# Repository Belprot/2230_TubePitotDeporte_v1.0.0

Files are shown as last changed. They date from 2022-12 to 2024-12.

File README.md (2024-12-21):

# 2230_TubePitotDeporte

Electronic system designed to measure historical aircraft stall data and transmit them via Bluetooth to an application that displays and records the values.

## [Project report](doc/Versions/2230_TubePitotDeporte_Rapport_Final_v1_0_0.pdf)

## Project poster
1696542741941-cd63cdde-709c-4f6f-9c06-00f6e5ce87d3_1

## 3D PCB pictures
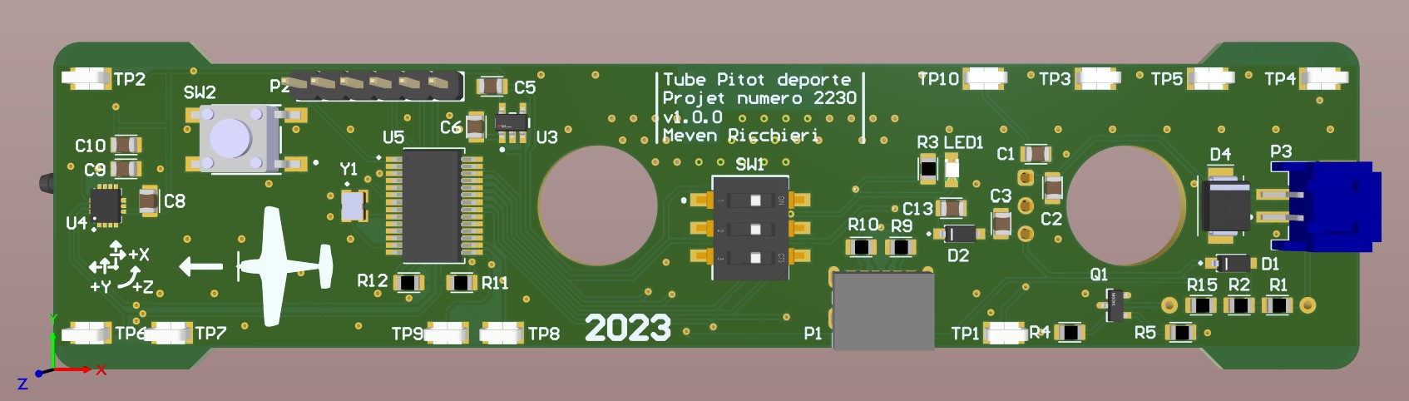
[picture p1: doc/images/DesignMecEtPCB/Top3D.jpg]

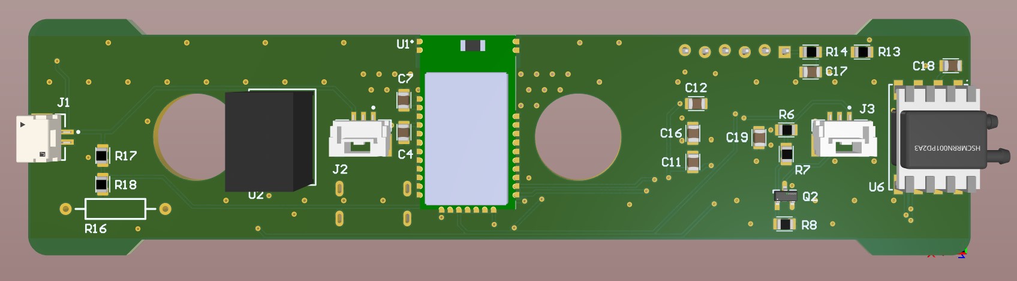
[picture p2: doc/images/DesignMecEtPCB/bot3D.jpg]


## 3D Integration
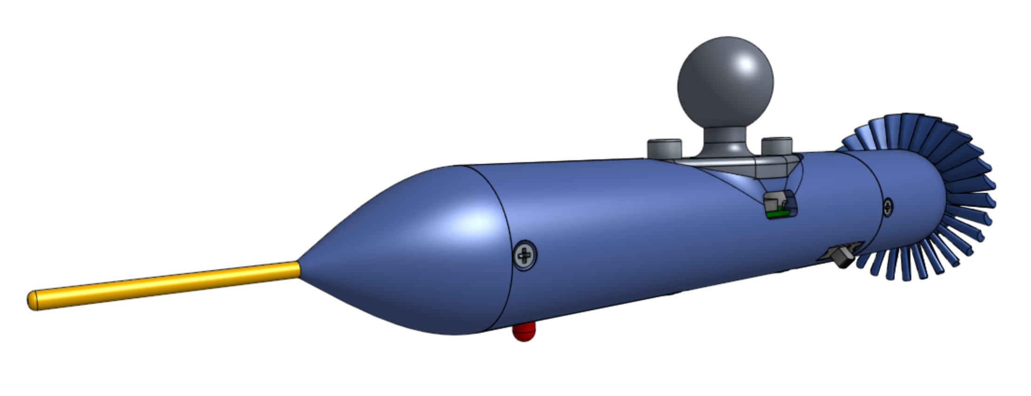
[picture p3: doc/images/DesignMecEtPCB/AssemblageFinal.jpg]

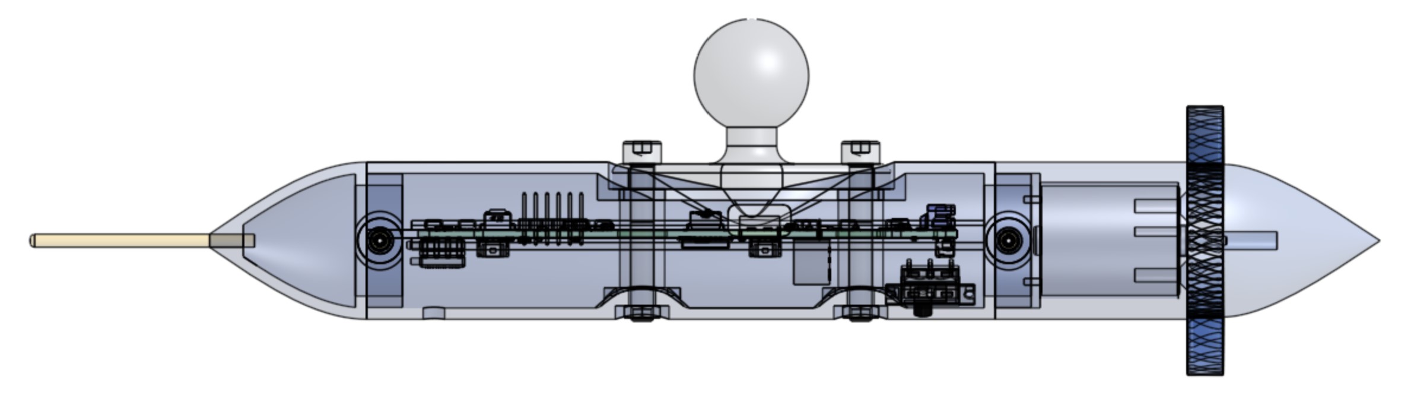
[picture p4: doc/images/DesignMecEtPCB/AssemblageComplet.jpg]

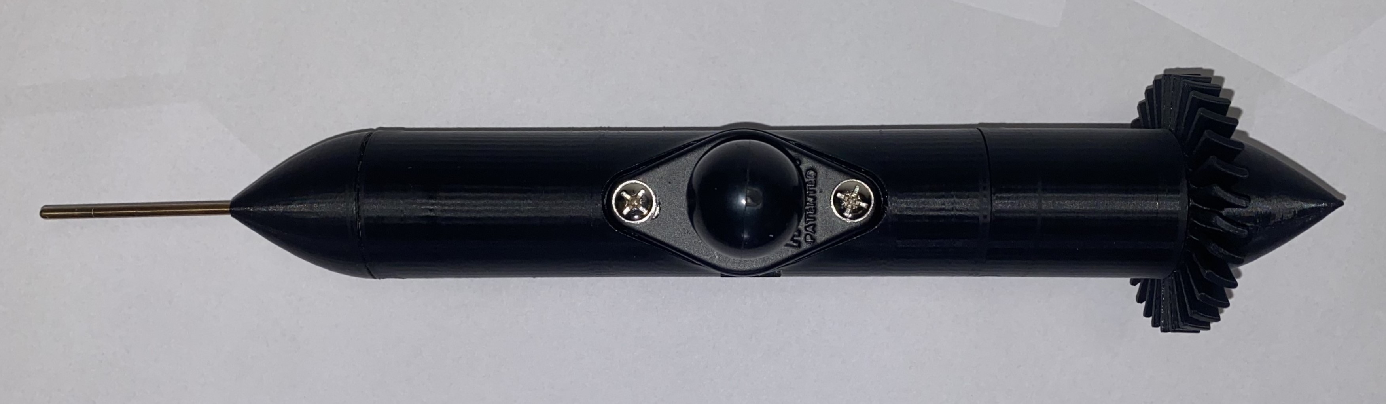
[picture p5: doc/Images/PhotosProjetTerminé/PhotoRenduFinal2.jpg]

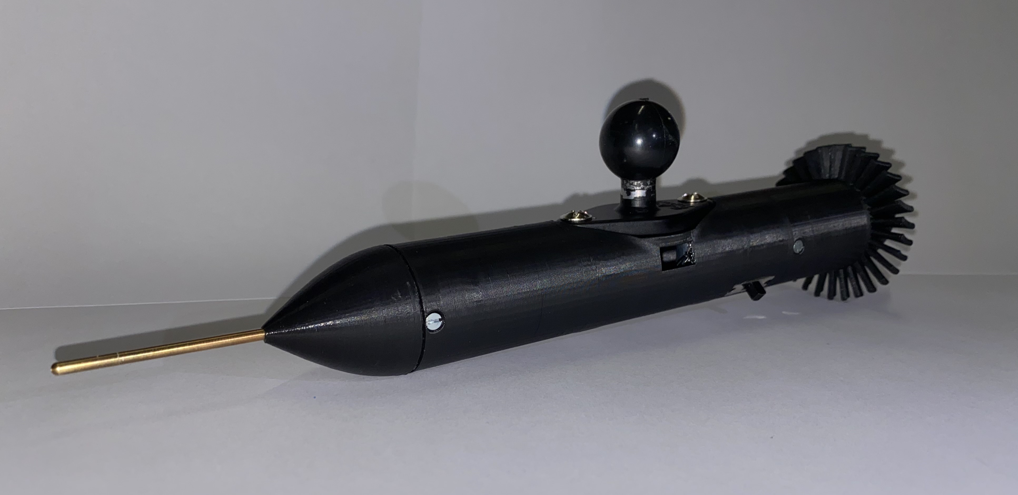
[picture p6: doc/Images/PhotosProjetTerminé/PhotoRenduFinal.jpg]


## Application preview
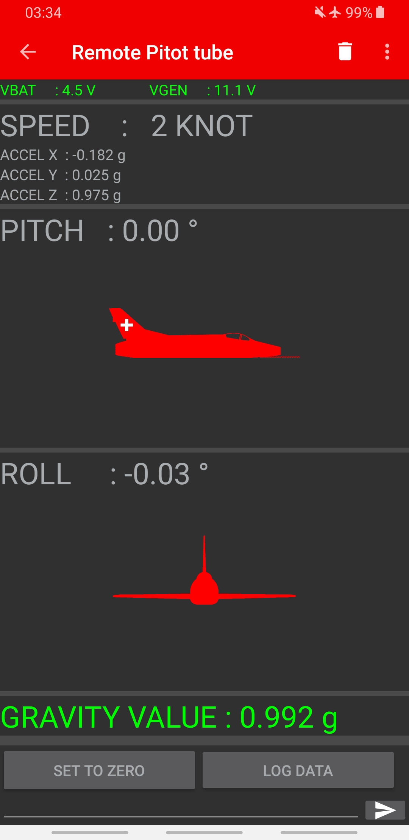
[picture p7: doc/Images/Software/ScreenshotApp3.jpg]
Application preview


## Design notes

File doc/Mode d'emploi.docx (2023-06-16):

# Mode d’emplois :

1. Branchez le connecteur de la batterie.
2. Vissez le support pile au boitier principale.
3. Allumez le système à l’aide du switch.
4. Appairez le système à l’appareil Android.
5. Lancez l’application dédiée.

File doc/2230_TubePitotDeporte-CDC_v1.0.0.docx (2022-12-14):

# Projet ETML-ES - Cahier des charges

Tube Pitot déporté

2230

A remplir par l'initiateur / porteur de projet

Entreprise/Client: | | Département:
Demandé par (Prénom, Nom): | | Date:

A remplir par le gestionnaire de projet (étudiant)

Auteur (ETML-ES): | Meven Ricchieri | Filière: | SLO
| | Date: | 16.11.2022

# 1 But du projet

Le but du projet consiste à développer un système permettant de détecter l’angle d’incidence et la vitesse au décrochage d’un avion. La fixation de ce système doit être flexible afin de pouvoir l’installer sur différents types d’avions. L’emplacement de fixation ne doit pas se trouver dans le flux d’air provenant de l’hélice afin d’éviter que la mesure de vitesse ne soit faussée. Il doit également être miniaturisé au maximum afin de produire le minimum de trainée possible et de ne pas dépasser un poids de 500g. Les données acquises par les capteurs doivent être transmises de la partie déportée à un appareil Android se trouvant dans le cockpit de l’avion au travers une communication sans fil. L’appareil Android doit traiter et afficher les données reçues, si possible graphiquement (optionnel).

## 1.1 Schéma de principe

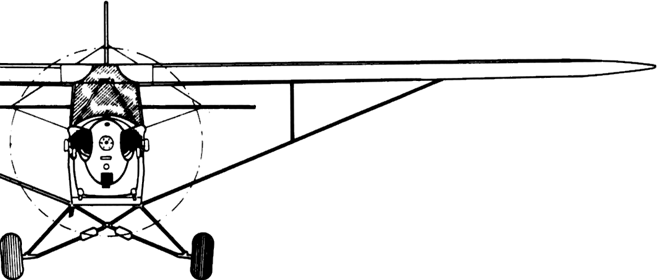
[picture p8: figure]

3

1 : Produit

2 : Appareil Android

3 : Signaux BLE (Bluetooth Low Energy)

1

2

Figure 1 -

# 2 Spécifications du projet

## 2.1 Schéma bloc

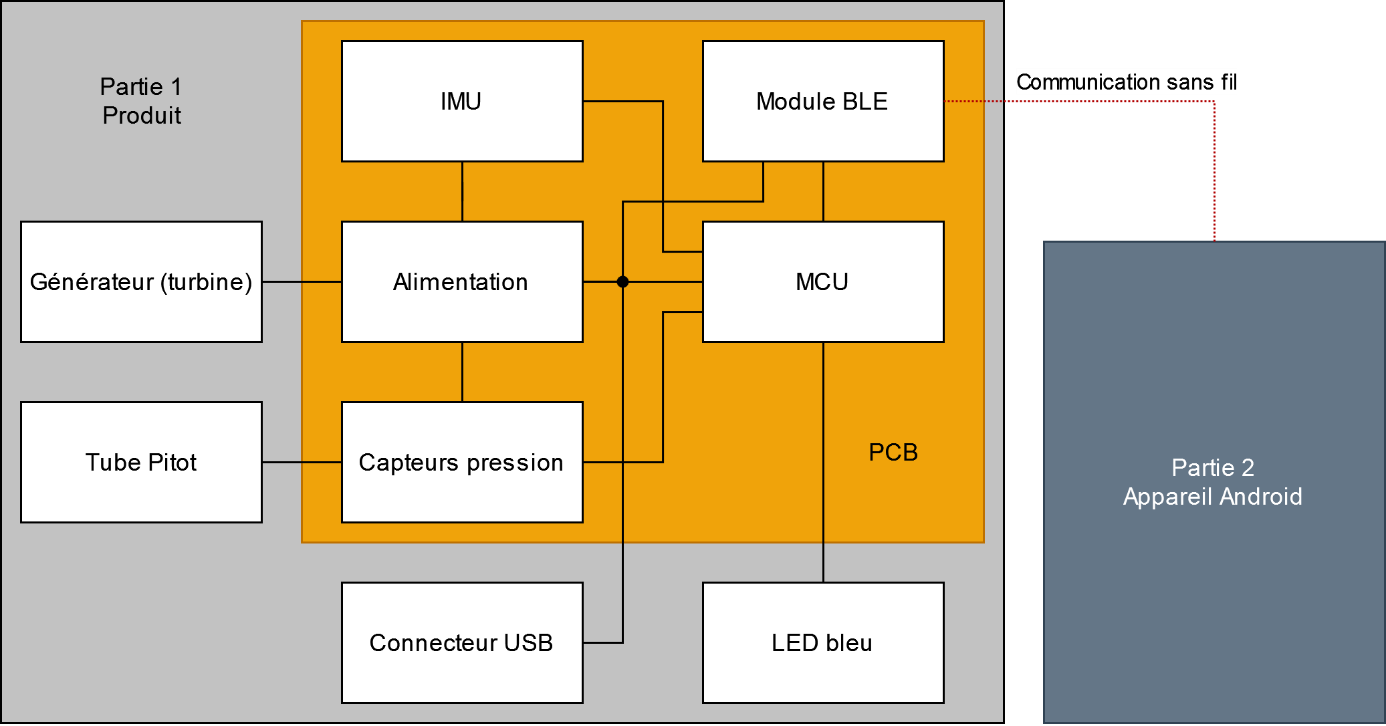
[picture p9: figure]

Figure 2 - Schéma bloc

### 2.1.1 Descriptions simples des blocs

- Générateur (turbine), l’idée est d’intégrer un générateur-turbine, montés à l’arrière du produit (voir Figure 2) afin de générer l’électricité nécessaire au système. Dans le cas où la réalisation mécanique de cela serait trop difficile, une batterie ou pile serait l’alternative.
- LED bleue, permettra d’indiquer l’état du système à un moment donné, elle devra être visible depuis l’intérieur du cockpit. Le comportement sera le suivant :
  - LED éteinte, le système non alimenté.
  - Simple clignotement à une fréquence de 0.5Hz, le système n’est pas appairé à un périphérique Bluetooth.
  - Double clignotement à une fréquence de 0.5Hz, le système est appairé à un périphérique Bluetooth et fonctionnel.
- Connecteur USB, le connecteur permettra d’alimenter le système afin de le tester lorsqu’il est au sol.
- Tube Pitot, servira d’entrée d’air pour les capteurs de pression.
- Capteurs pression, ces capteurs liront les valeurs de la pression statique et totale pour ainsi calculer la vitesse air.
- Alimentation, l’alimentation transformera la tension provenant de la source d’énergie en une tension régulée et stable.
- IMU, la centrale inertielle servira à mesurer les vecteurs des vitesses angulaires et les accélérations.
- MCU, le microcontrôleur va être le cerveau du produit, il sera responsable de commander tous les autres composants.
- Module BLE, le module Bluetooth Low Energy permettra d’établir une communication basse consommation entre le produit et l’appareil Android. C’est par le biais de cette liaison que seront transmises toutes les données.
- Appareil Android, l’appareil recevra, traitera et affichera les données sur son écran. Il permettra également d’envoyer des commandes tels que la fréquence d’envoi ou d’autres paramètres.

Les blocs seront décrits en détail dans la pré-étude.

## 2.2 Croquis du produit

L’intégration du système se fera dans un cylindre à l’arrière du tube Pitot comme représenté ci-dessous (vue en coupe). Dans le cas où la vitesse de rotation du générateur est trop élevée, l’ajout d’un carénage permettrait de diminuer la vitesse du flux d’air en augmentant la section de sortie par rapport à l’entrée. La fixation se réalisera à l’aide d’une boule style RAM-Mounts.

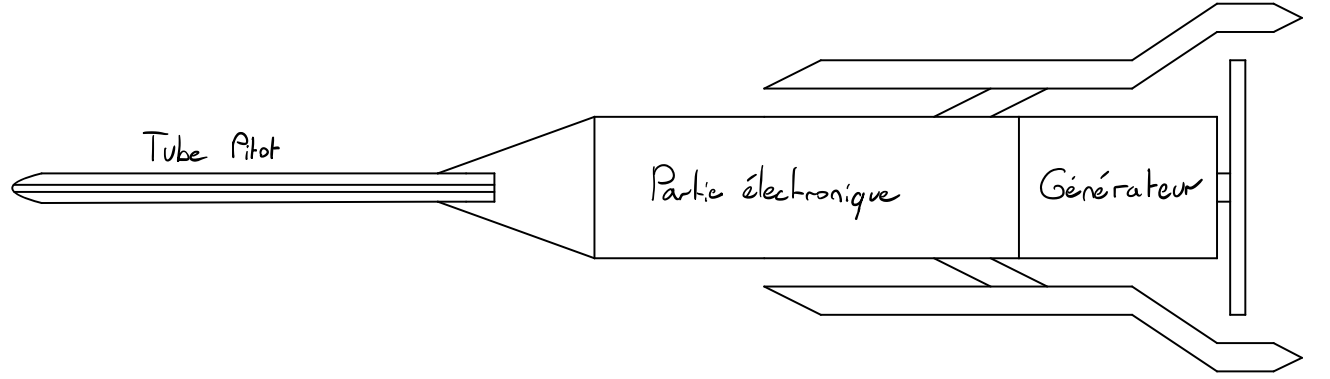
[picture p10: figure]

Figure 3 - Croquis du produit (vue en coupe)

# 3 Tâches à réaliser

- Pré-étude
- Dimensionnement, design et réalisation du schéma
- Commande des composant et du matériel
- Réalisation du PCB
- Design de l’assemblage mécanique avec fixations
- Montage du PCB
- Réalisation du software du MCU et de l’application Android
- Impression 3D ou usinage de la partie mécanique
- Mise en service et tests

# 4 Deadlines principales

- 16 novembre 2022 : Début du projet
- 07 décembre 2022 : Rendu de la pré-étude
- 14 décembre 2022 : Présentation de la pré-étude
- 25 janvier 2023 : Rendu du design
- 01 février 2023 : Présentation du design
- 22 mars 2023 : Rendu des fichiers de fabrication PCB
- 14 juin 2023 : Rendu de toute la documentation finale
- 21 juin 2023 : Présentation finale

## 4.1 Planning

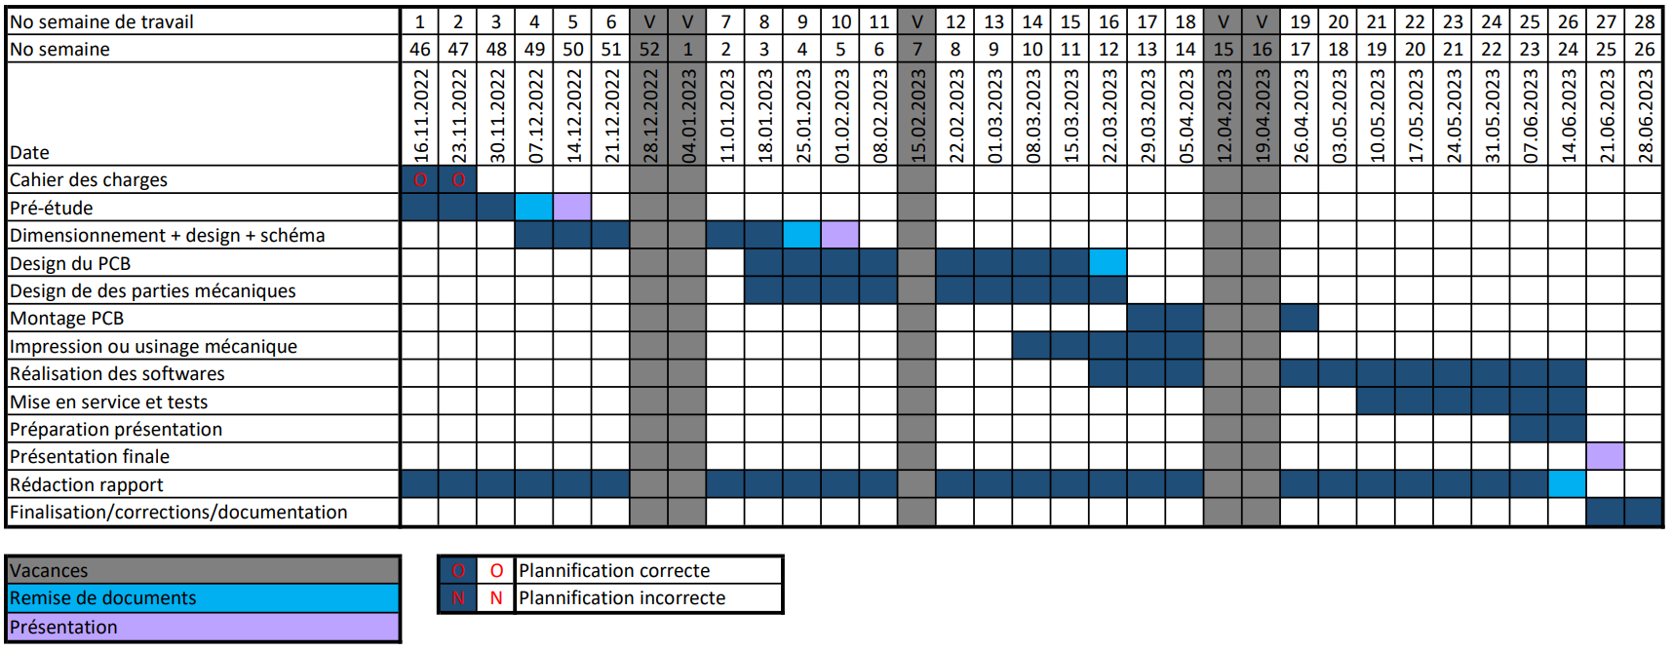
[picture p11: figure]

Figure 4 - Planning

# 5 Livrables

- Les fichiers sources de CAO électronique et mécanique
- Tout le nécessaire pour fabriquer un (1) exemplaire hardware :
  - Fichiers de fabrication (GERBER)
  - Liste de pièces avec références (BOM)
  - Implantation des composants
  - Dessins mécaniques
- Les fichiers sources de programmation du microcontrôleur (.c/.h)
- Tout le nécessaire pour programmer les microcontrôleurs (.hex)
- Les fichiers sources de programmation Android.
- Tout le nécessaire à l’installation de programmes sur Android.
- Un mode d’emploi du produit
- Une estimation des coûts du projet
- Un rapport contenant toutes les informations du design du produit.
- Un prototype monté et fonctionnel
- Une application Android permettant d’afficher les données :
  - Affichage numérique
  - Affichage graphique (optionnel)

JMO – Nov 20222230_TubePitotDeporte-CDC-v1.0.0.docxPage 4

ECOLE SUPERIEURE PROJ – SLO

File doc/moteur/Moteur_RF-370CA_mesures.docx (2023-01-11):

Données fournies par le fabriquant du moteur :

Introduction :

Les mesures sont réalisées en deux parties, la première permet d'obtenir des valeurs précises de la vitesse de rotation en fonction de la tension d'alimentation et la deuxième permet de connaitre la tension générée lorsque les vitesses sont les mêmes qu'à la première partie.

Méthode de mesures partie 1 :

Le moteur RF-370A-15370 est connecté à une alimentation DC, celle-ci délivre une tension de 0 à 12V par pas de 1V. A chaque saut de tension, la vitesse est mesurée à l'aide d'un tachymètre optique.

Schéma de mesures partie 1 :

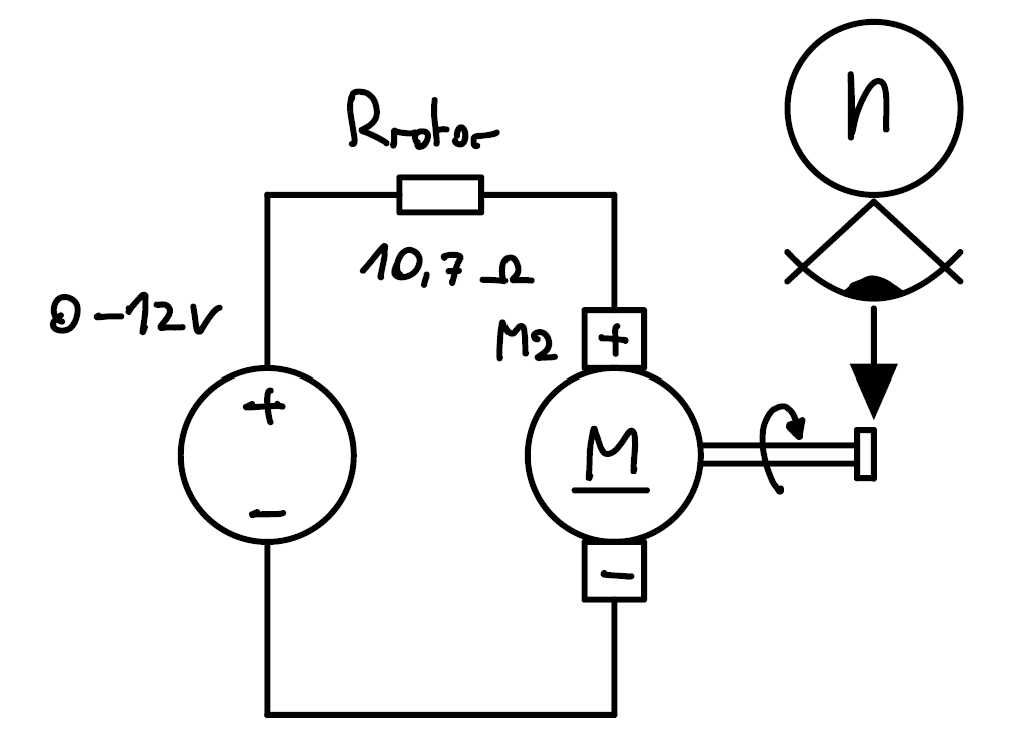
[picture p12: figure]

Uin

Résultats partie 1 :

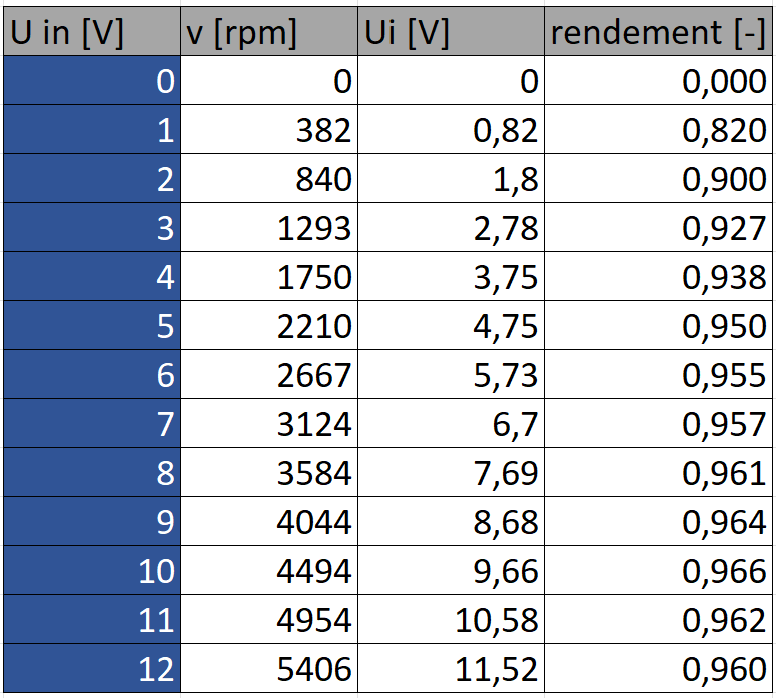
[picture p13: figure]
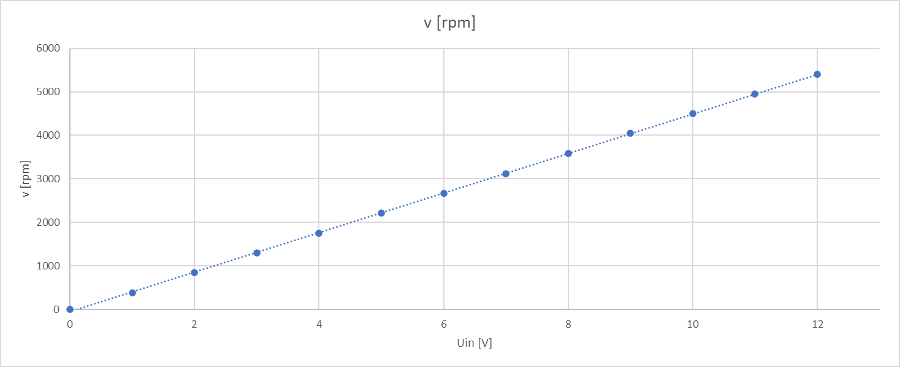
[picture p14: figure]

Méthode de mesures partie 2 :

Pour cette deuxième partie, le un banc de test est composé d’un deuxième moteur DC qui permet d’entrainer le moteur RF-370A-15370. Le moteur M1 est alimenté avec une tension DC alors que le moteur M2 (RF-370A-15370) génère une tension en fonction de sa vitesse de rotation.

Schéma de mesure partie 2 :

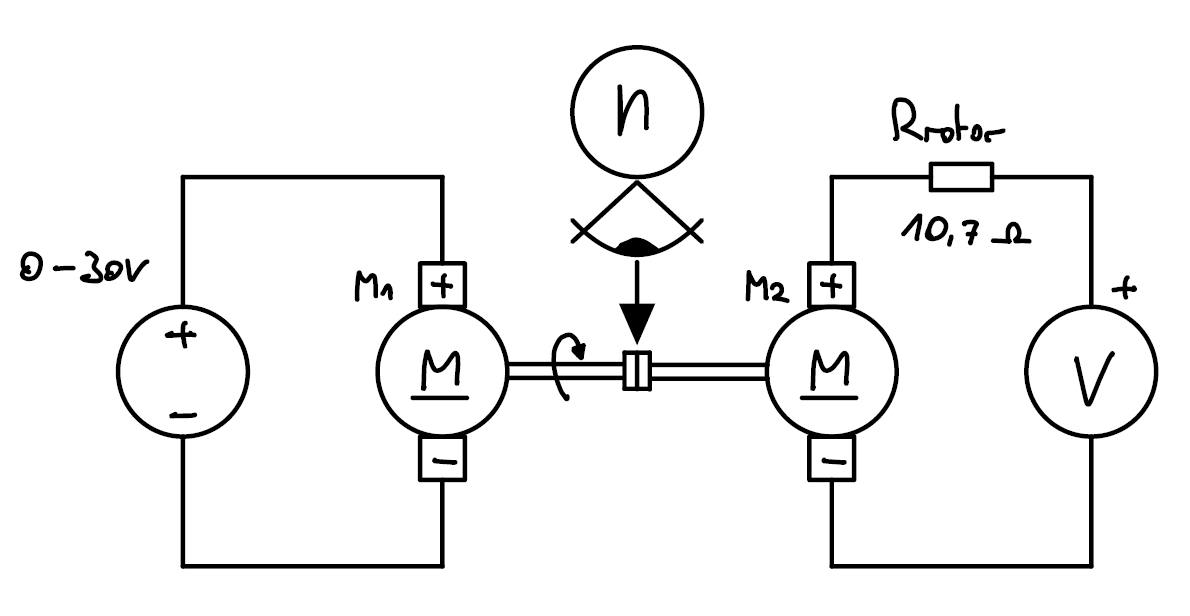
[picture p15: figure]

UT

Résultats partie 2 :

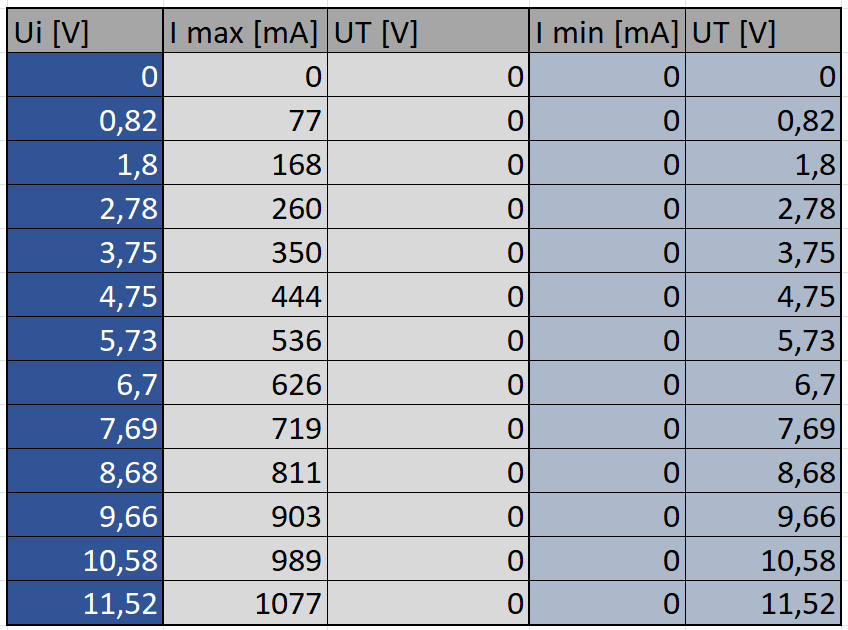
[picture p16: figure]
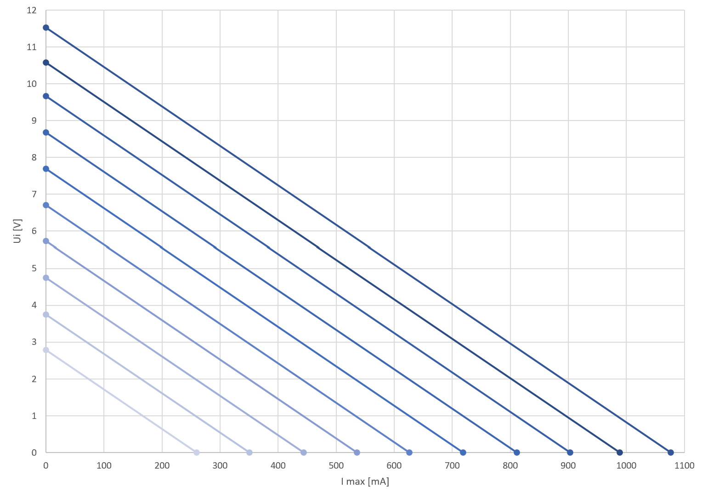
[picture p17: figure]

Delémont, le 27 décembre 2022 Meven Ricchieri

Caractérisation moteur RF-370A-15370 27.12.2022

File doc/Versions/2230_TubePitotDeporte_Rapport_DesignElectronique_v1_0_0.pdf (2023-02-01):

# Tube Pitot déporté

Détection de l’angle d’incidence au décrochage d’un avion par mesure de la vitesse et des accélérations

Meven Ricchieri
2022 - 2023
Numéro de projet | : | 2230
Responsable | : | M. Juan José Moreno
Mandataire | : | M. Vincent Seguin (pour AMPA)

2230_TubePitotDeporte-Rapport_v1.0.0

## Table des matières

1 Cahier des charges | 2
2 Pré-étude | 2
3 Design électronique | 9
4 Annexes | 19

## 1 Cahier des charges

Le but du projet consiste à développer un système permettant de détecter l’angle d’incidence et la vitesse au décrochage d’un avion. La fixation de ce système doit être flexible afin de pouvoir l’installer sur différents types d’avions. L’emplacement de fixation ne doit pas se trouver dans le flux d’air provenant de l’hélice afin d’éviter que la mesure de vitesse ne soit faussée. Il doit également être miniaturisé au maximum afin de produire le minimum de traînée possible et de ne pas dépasser un poids de 500g. Les données acquises par les capteurs doivent être transmises de la partie déportée à un appareil Android se trouvant dans le cockpit de l’avion au travers une communication sans fil. L’appareil Android doit traiter et afficher les données reçues, si possible graphiquement (optionnel).

Le cahier des charges complet se trouve en annexes.

## 2 Pré-étude

### 2.1 Contexte

Cette pré-étude consiste à mener des recherches qui conduirons à une décision de lancer ou non le projet. Cette décision va reposer sur les difficultés de réalisation électrique, mécanique et software. Elle va aussi permettre d’imaginer et de comparer les différentes manières de réaliser les tâches et ainsi choisir la meilleure.

### 2.2 Schéma de principe

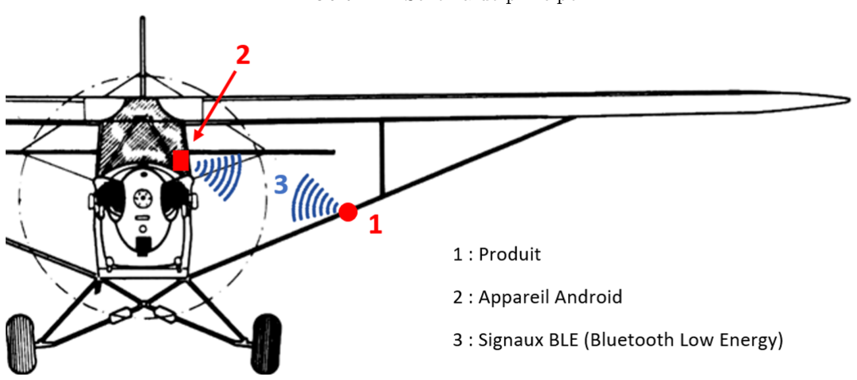
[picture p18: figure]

Figure 1 – Schéma de principe

### 2.3 Schéma bloc détaillé

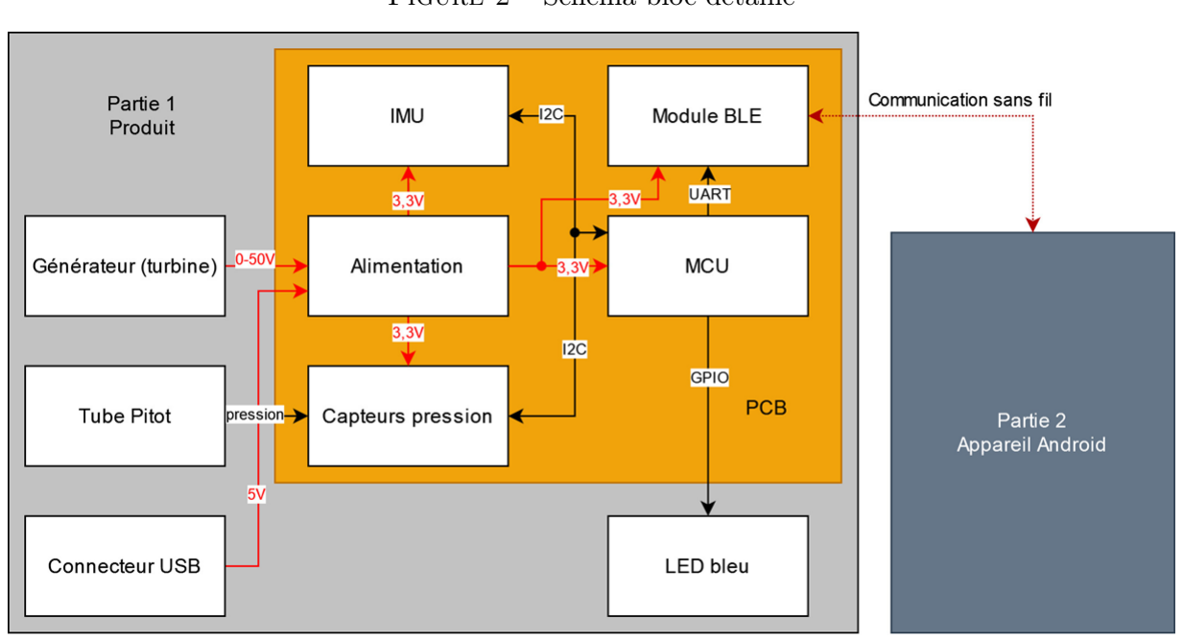
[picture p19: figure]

Figure 2 – Schéma bloc détaillé

### 2.4 Descriptions des blocs détaillées

### 2.4.1 Bloc Générateur (turbine)

L’intérêt d’utiliser un générateur comme source d’énergie permet de simplifier l’utilisation du système, il n’y aura aucune maintenance à effectuer ou de batterie à charger. L’énergie cinétique de l’air en mouvement, par rapport à l’avion, vas être captée par les aubes de la turbine axée à un générateur, ce qui va produire une tension. Le système va se mettre en marche une fois que l’axe du générateur-turbine aura atteint une certaine vitesse de rotation. Plus la vitesse sera grande, plus la tension générée sera élevée. Un simple moteur DC, va permettre de transformer cette énergie mécanique en énergie électrique. Il est possible d’utiliser d’autres technologies comme les moteurs brushless, qui ont un rendement bien meilleur, mais cela complexifie le circuit et augmente le prix. Dans ce projet, le rendement n’est pas primordial car le système ne consommera que très peu d’énergie.
Ut(V ) = n
kn
− Rmot ∗ IL [2] | (1)

où :
Ut | = | Tension aux bornes du moteur DC (V)
kn | = | Constante de vitesse du moteur DC (rpm/V)
Rmot | = | Résistance aux bornes du moteur DC (Ω)
n | = | Vitesse moteur DC (rpm)
IL | = | Courant de charge (I)

Puisque la valeur de la tension géné-

rée est dépendante de la vitesse air de l’avion, celle-ci ne sera jamais stable. Il faudra donc la transformer et la réguler avant de la transmettre aux composants électroniques, ce à quoi le bloc "Alimentation" sera destiné.

N’ayant pas de grandes connaissances dans le dimensionnement et le design de générateur-turbines, des recherches plus poussées seront nécessaires afin de rendre le système performant. Pour me faire une première idée, j’ai dessiné et imprimé une première turbine composée de 13 aubes puis j’ai effectué quelques tests. A l’aide d’un moteur DC, j’ai réussi à générer une tension d’environ 3V à une vitesse de 80km/h.

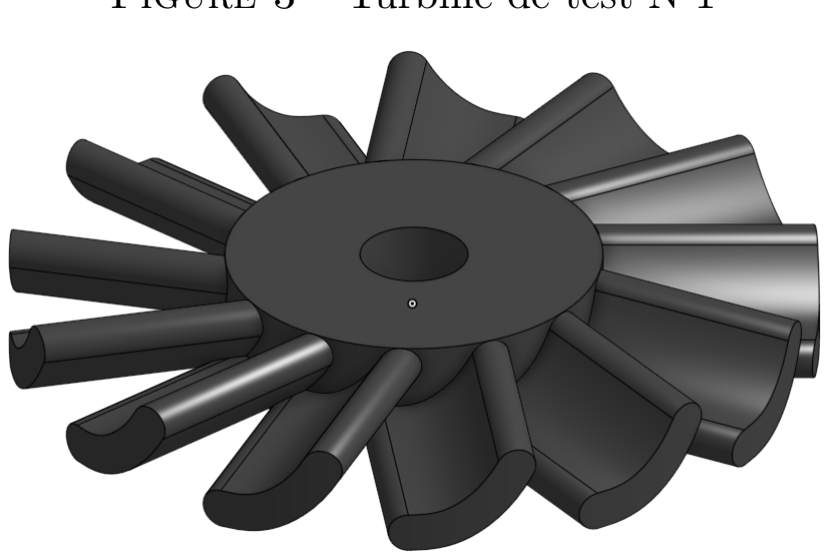
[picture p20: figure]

Figure 3 – Turbine de test N°1

### 2.4.2 Bloc Capteur de pression

Le système sera équipé d’un capteur de pression différentielle qui permettra de mesurer la différence entre la pression statique et la pression totale. "La pression statique, dans un fluide en mouvement, est la pression que mesure un capteur qui se déplace à la même vitesse que le fluide" [3]. "La pression totale dans un fluide (eau, air, etc.) est la somme de la pression statique, de la pression dynamique, et de la densité volumique d’énergie potentielle de gravité" [4]. Grâce aux valeurs ainsi mesurées, il sera possible de calculer la vélocité du fluide, ce qui correspondra à la vitesse air de l’avion. Pour des vitesses inférieures à Mach 0.3 (200 nœuds), l’effet de compressibilité du fluide peut être négligé [5].

v(m/s) = s
2 ∗ (pt − ps)
ρ
[5] (2)

où :
v | = | Vélocité du fluide (m/s)
pt | = | Pression totale (Pa)
ps | = | Pression statique (Pa)
ρ | = | Masse volumique du fluide (kg/m³
)

### 2.4.3 Bloc Tube Pitot

Comme expliqué au point précédent, la vitesse se calcule grâce à la pression statique et totale, pour que le capteur différentielle ait accès à ces deux pressions, il faut ajouter deux entrées d’air. Ces entrées doivent être placées correctement car dans le cas contraire, la vitesse calculée ne sera pas correcte. L’entrée de la pression statique doit être perpendiculaire à l’écoulement local du fluide (non perturbé) alors que celle de la pression totale doit être parallèle à ce flux. Il existe 3 tubes différents, le premier, appelé tube Pitot simple, est simplement un tube perforé en son centre faisant office d’entrée d’air pour la pression totale. Le second, appelé sonde statique, est perforé latéralement permettant l’entrée d’air pour la pression statique. Le troisième est une combinaison des deux premiers, il dispose d’une entrée pour la pression totale et d’une autre pour la pression statique. L’idéal serait d’utiliser ce dernier car il simplifierait l’implémentation mécanique du système. Les deux sorties du tube seraient reliées au capteur de pression différentielle par des tuyaux. Dans le cas ou un tube Pitot simple serait utilisé, il serait nécessaire de perforer le boîtier du produit afin d’avoir accès à la pression statique. La décision du type de tube sera effectué lors du design mécanique car il n’influence aucunement la conception électronique.

Figure 4 – Types de tubes Pitot

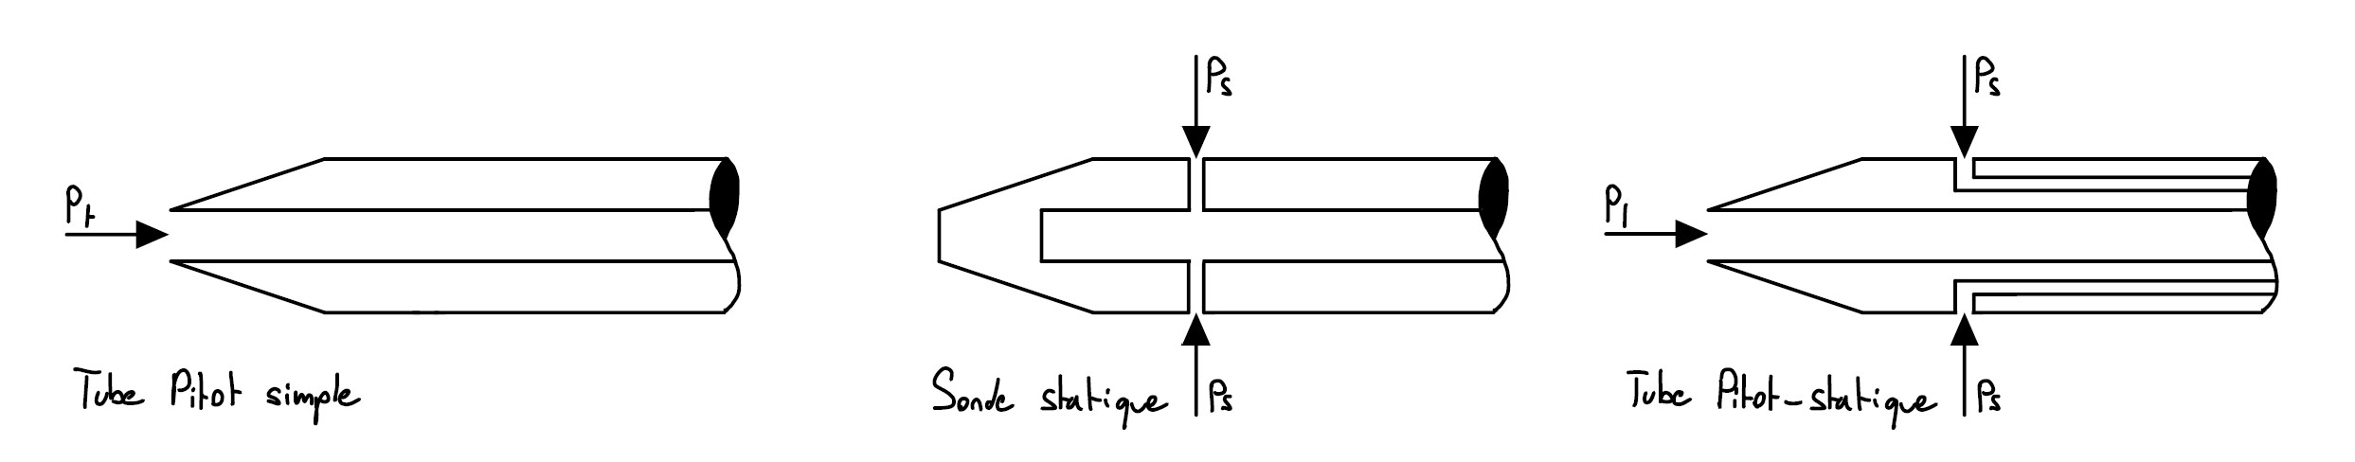
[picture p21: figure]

### 2.4.4 Bloc IMU

La centrale inertielle comportera 6 capteurs, 3 gyromètres et 3 accéléromètres. "Les gyromètres mesurent les trois composantes du vecteur vitesse angulaire (vitesses de variation des angles de roulis, de tangage et de lacet. Les accéléromètres mesurent les trois composantes du vecteur force spécifique. La force spécifique est la somme des forces extérieures autres que gravitationnelles divisée par la masse" [1]. C’est grâce à ses capteurs qu’il sera possible de détecter le moment où l’avion commence à décrocher. La plupart de ces IMUs ont également un capteur de température intégré, la mesure de cette grandeur peut être intéressante puisqu’elle a une influence sur la valeur de la pression.

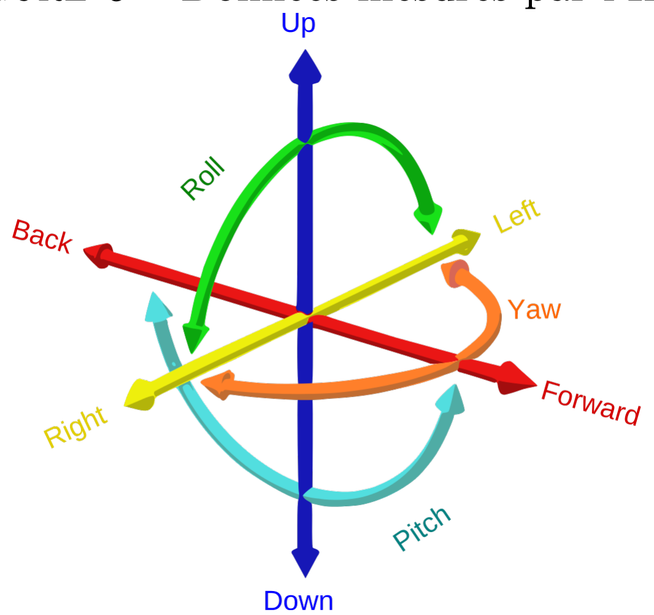
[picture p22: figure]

Figure 5 – Données mesurés par l’IMU

### 2.4.5 Bloc Connecteur USB

Étant donné que le système n’aura pas de source d’énergie interne, un connecteur USB-C sera implémenté afin de pouvoir tester la communication ainsi que les capteurs, en amont du vol. Il permettra également d’alimenter le système lors de son installation sur l’avion, car il devra être positionné correctement à l’horizontale pour que les mesures soient fiables.

### 2.4.6 Bloc Module BLE

Le transfert de données entre le produit et l’appareil Android, se fera au travers d’une communication sans fil Bluetooth Low Energy (BLE). Cette variante de Bluetooth permet de réduire significativement sa consommation par rapport au mode normal. Il sera tout de même possible qu’un module permettant de choisir le mode de fonctionnement soit implémenté. Les données transmises du produit à l’appareil Android seront principalement les valeurs lues par les capteurs alors que celle provenant de l’appareil seront plutôt des commandes ou réglages.

### 2.4.7 Bloc LED bleue

Comme énoncé dans le CDC, la LED bleue va permettre d’indiquer l’état du système. La LED éteinte va signifier que le système n’est pas alimenté. Un clignotement toute les 2 secondes correspondra au système alimenté mais non appairé à un périphérique Bluetooth et finalement, 2 clignotements toute les 2 secondes correspondra à l’état fonctionnel, appairé et transmettant les données. La LED devra être visible de jour donc son emplacement et son intensité lumineuse devront être correctement défini.

### 2.4.8 Bloc MCU

Le microcontrôleur sera obligatoirement un modèle 32Bit du fabriquant Microchip. Il va faire le lien entre tous les périphériques implémentés, c’est à dire les composants d’entrées, IMU et capteur de pression et ceux de sortie, module BLE et LED. Selon les recherches effectués précédemment, le microcontrôleur devra au minimum contenir,

— Un module UART pour la communication avec le module Bluetooth
— Un module I2C pour la communication avec l’IMU et le capteur de pression — Une PIN GPIO pour le contrôle de la LED

### 2.4.9 Bloc Alimentation

Puisque la grande majorité des composants nécessaires, tel que le PIC ou les capteurs, fonctionnent avec une tensions de 3.3V, il faudra donc que la sortie de ce bloc soit proche de cette valeur. Le générateur va produire une tension bien supérieur à 3.3V, donc la meilleure option est d’utiliser un convertisseur Buck afin de l’abaisser. Il permettra d’avoir un bien meilleur rendement qu’un régulateur linéaire et donc limiter la consommation.

Composant | min | max
Module BLE (consommation non continue) Microcontrôleur Capteur pression différentielle LED (consommation non continue) Centrale inertielle | 5mA 5mA 3mA 10mA 1mA | 10mA 10mA 4mA 20mA 3mA
Total | 24mA | 47mA

La consommation totale devrait se situer entre 24mA et 47mA

### 2.4.10 Bloc Appareil Android

Toutes les données obtenues au travers de la communication sans fil seront traitées et affichées sur l’écran de l’appareil. Ces données seront affichées sous forme numérique et dans l’idéal, sous forme graphiques, mais cela reste optionnel. L’application permettra d’envoyer certaines commandes au produit en appuyant sur les différents boutons qui seront affichés. Il sera aussi possible d’ajouter une valeur d’offset aux mesures pour compenser une éventuelle erreur.

### 2.5 Design mécanique

Comme expliqué dans le cahier des charges, l’idée est d’adapter tout le système pour qu’il puisse se trouver dans un cylindre à l’arrière du tube Pitot. Le boîtier et les autres parties mécaniques seront imprimé en une matière plastique selon la disponibilité de matériaux de l’école. L’idéal serait d’utiliser de l’acrylonitrile butadiène styrène (ABS) car ses caractéristiques mécaniques sont bien supérieures à l’acide polylactique (PLA). La grosse difficulté va être de miniaturiser le design du PCB afin de rendre la section du tube la plus mince possible. Le système de fixation sera réalisé grâce à une boule style RAM-Mounts vissé au boîtier.

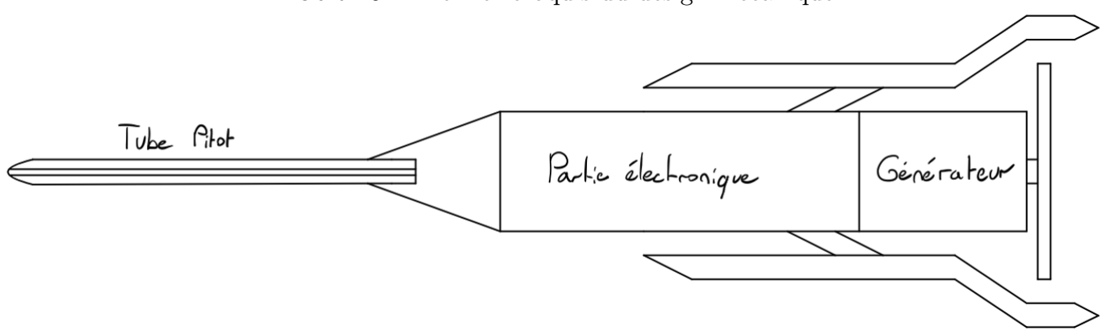
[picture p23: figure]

Figure 6 – Premier croquis du design mécanique

### 2.6 Estimation du prix

L’estimation du prix est actuellement difficile car certains choix doivent encore êtres pris et la disponibilité des composants peut avoir une influence, j’ai donc mis un plage de prix.

Composant | min | max
Générateur (moteur DC) Turbine (ABS) Capteur pression différentielle Tube Pitot Centrale inertielle Connecteur USB-C Module Bluetooth LED MCU Convertisseur Buck Boîtier (ABS) Boule RAM-Mounts PCB | 5.-0.5.-30.-0.-5.-1.-5.-0.5.-1.-3.-1.-15.-50.- | 50.-1.-70.-30.-12.-3.-15.-3.-3.-8.-2.-25.-75.-
Total | 126.- | 396.-

Le prix devrait se situer entre 126.- et 396.-

### 2.7 Faisabilité du projet

D’après les informations trouvées, le projet est totalement réalisable. Il y aura sans doutes quelques difficultés au niveau du dimensionnement de la partie turbine-générateur.

## 3 Design électronique

### 3.1 Introduction

La partie Design électronique consiste à réaliser le schéma électrique, choisir les composants et réaliser les dimensionnements nécessaires. Certaines modifications ont suivi la présentation de la pré-étude. Ceux-ci concernent :
- la source d’alimentation
- la régulation de tension

### 3.2 Générateur

Selon l’estimation de consommation totale effectuée lors de la pré-étude, il est maintenant possible de calculer approximativement la puissance minimum que le générateur devra délivrer au système.

P(W) = U ∗ I | (3)

où :
P | = | Puissance nécessaire (W)
U | = | Tension du circuit (V)
I | = | Courant consommé (A)

Avec la formule (3) :
| | P(W) = 3.3 ∗ 0.047 = 0.1551W = 155mW

Les 155mW correspondent à la puissance maximale approximative consommée après transformation, ce qui signifie qu’il y aura quelques pertes au niveau des abaisseurs de tension. Afin de ne pas avoir de mauvaises surprises, j’ai décidé de prendre une certaine marge, au lieu de 155mW, la puissance sera de 250mW. Cette puissance étant tout de même très faible, le système sera capable de fonctionner même à faibles vitesses tant que la tension minimale est atteinte. Ayant effectué des tests lors de ma pré-étude avec un moteur 3VDC et une première turbine, mon professeur M.Moreno m’en a fourni un différent, RF-370A-15370, fonctionnant jusqu’à une tension nominale de 12VDC. Pour vérifier si ce moteur pourra être utilisé, j’ai réalisé quelques mesures et calculs afin de visualiser les lignes de tension-courant du générateur.

Figure 7 – Lignes tension-courant du générateur

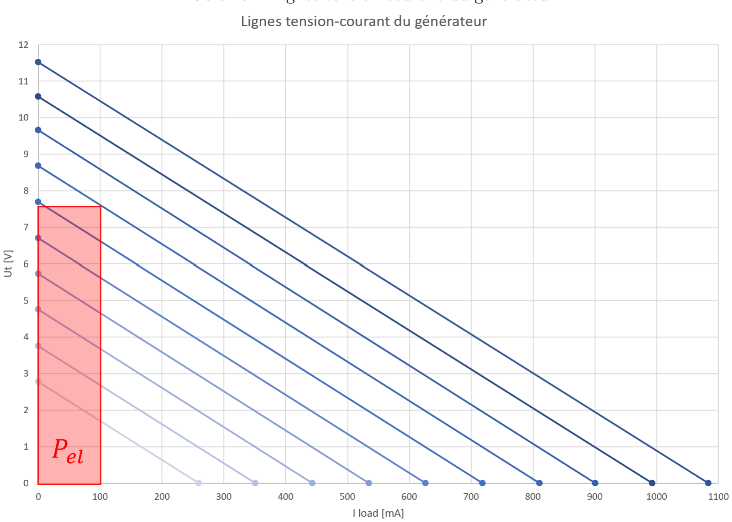
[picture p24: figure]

Le rectangle rouge sur la figure 7 permet de visualiser la puissance électrique. Avec celle-ci nous pouvons savoir quelle tension sera disponible au borne du moteur en fonction de la vitesse de rotation (tension à vide) et du courant consommé. Le rectangle actuel montre que la tension est d’environ 7.8V lorsque la tension à vide est de 8V (environ 3600rpm) avec un courant consommé de 100mA.
Avec la formule (3) :
P(W) = 7.8 ∗ 0.100 = 0.78W = 780mW

Avec ce calcul, il est évident que le moteur correspond parfaitement puisque celui-ci devra fournir bien moins de puissance au système. Ce moteur là est plus adapté car il génère une tension supérieurs à la tension après régulation, 3.3VDC.

Le problème de ce moteur est qu’au moment ou sa vitesse est trop élevée, cela peut le dégrader. J’ai donc décidé d’ajouter au schéma un système de freinage. La tension générée par le moteur passera par un pont diviseur avant d’entrer dans une entrée analogique du MCU. Une diode de protection permettra de court-circuiter la surtension lorsqu’elle est trop importante pour protéger le MCU. Une sortie PWM sera connectée à la gate d’un N-MOSFET afin de court-circuiter le moteur afin de le freiner lorsque la lecture de l’entrée analogique indiquera que la vitesse est trop élevée. La tension entrant dans le MCU ne pourra pas dépasser la tension max de 3.3V.

Figure 8 – Générateur, circuit de mesure et de freinage

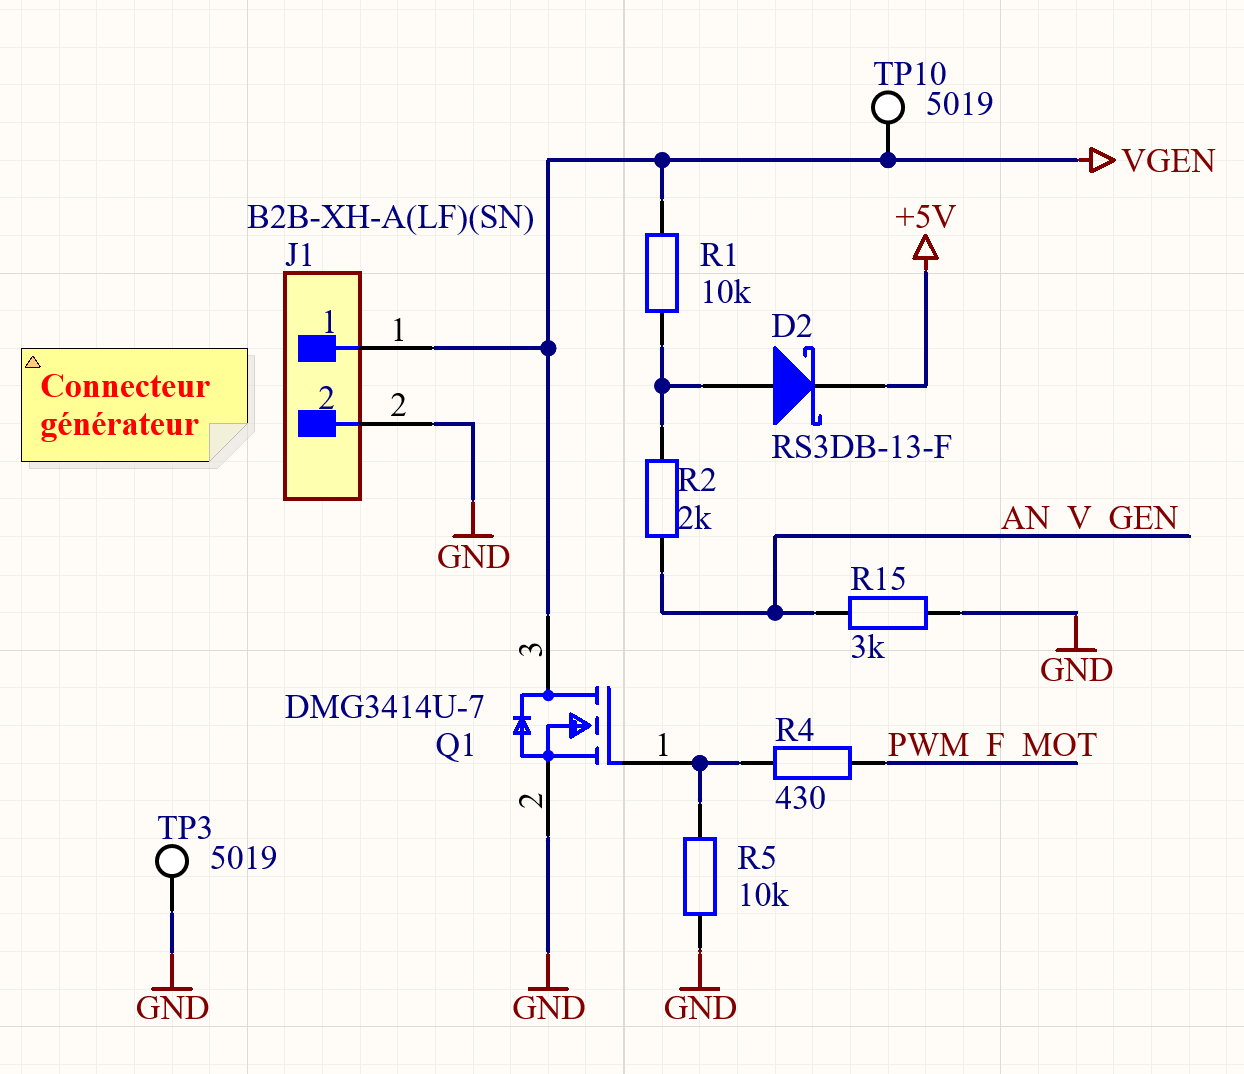
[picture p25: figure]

### 3.3 LED de signalisation

La LED de signalisation sera commandée par une GPIO du MCU et permettra d’indiquer l’état du système à l’utilisateur.

Figure 9 – LED de signalisation

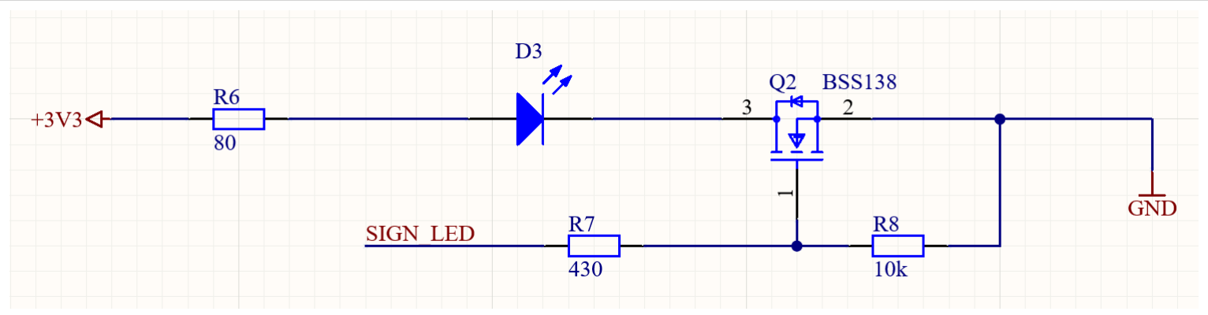
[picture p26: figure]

### 3.4 Piles

Suite à la présentation de ma pré-étude, il a été décidé que le produit possédera deux sources d’énergie différentes, l’intérêt est de rendre le système plus flexible. La première source sera celle de base, alimentation par un générateur-turbine, et la seconde sera une alimentation à piles rechargeables.

Les piles seront du type triple A de 1.5V chacune en série pour obtenir 4.5V en sortie. Celles-ci seront placées dans un support à piles cylindrique. La recharges des piles devra se faire séparément.

Figure 10 – Connecteur piles

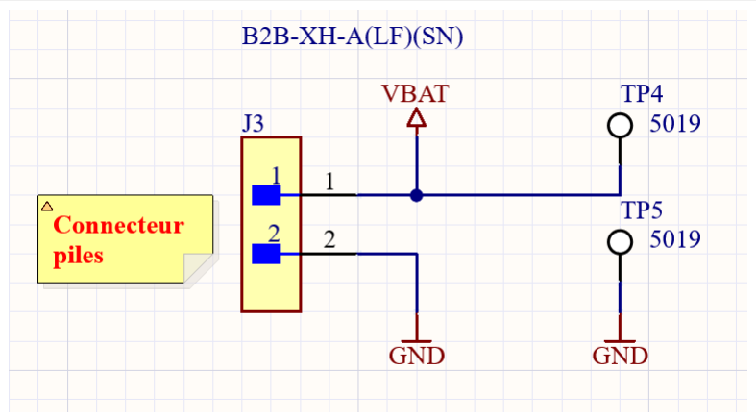
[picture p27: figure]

### 3.5 Capteur de pression

Le capteur de pressions différentielles choisi est le HSCMRRN001PD2A3 du fabriquant Honeywell. Il s’agit d’un capteur ayant 2 entrées d’air, une pour la pression statique et la seconde pour la pression totale. La communication se fera au moyen d’une liaison série I2C. Le composant ne nécessite pas de dimensionnement particulier au niveau hardware. Son adresse I2C est fixe et est 0b00101000 (0x28).

Product Series | HSC | High Accuracy, Compensated/Amplified
Package | M | SMT (Surface Mount Technology)
Pressure Port | RR | Dual radial barbed ports, same side
Options | N | Dry gases only, no diagnostics
Pressure Range | 001PD | ±1 psi (differential)
Output Type | 2 | I2C, Address 0x28
Transfer Function | A | 10% to 90% of Vsupply (analog), 214 counts (digital)
Supply Voltage | 3 | 3.3Vdc

La plage de pression différentielle mesurable de ce capteur est de ±1 psi, ce qui correspond à une pression de 6’894,76Pa.

Avec la formule (2) :

v(m/s) = r
2 ∗ 6
| | ′894, 76
| | 1.2 = 107.197m/s = 385.91km/h

En utilisant la formule de la vitesse cité lors de la pré-étude, la vitesse maximale mesurable avec ce capteur est de 385.91km/h.

Figure 11 – HSCMRRN001PD2A3

### 3.6 IMU

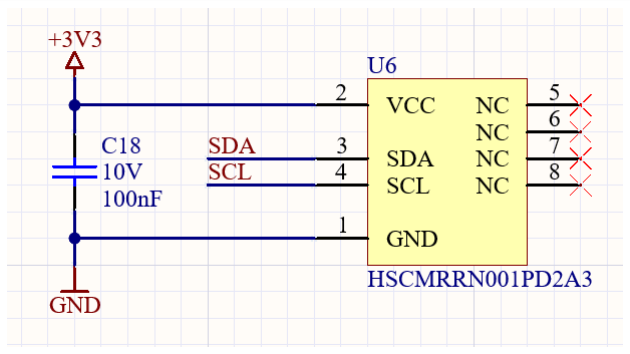
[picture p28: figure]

La centrale inertielle choisi est la ICM-42670-P du fabriquant TDK. Il s’agit d’un composant intégrant un gyroscope 3 axes et un accéléromètre 3 axes et ayant une très faible consommation. La communication se fera au moyen d’une liaison série I2C, son adresse est b01101000 (0x68) puisque sa PIN AP_AD0 est connecté volontairement à la masse.

Au niveau du gyroscope, les axes X, Y et Z ont une plage pleine échelle programmable de ±250, ±500, ±1000 et ±2000 degrés/sec. La plage des accélération en X, Y et Z est également programmable de ±2g, ±4g, ±8g et ±16g.

Figure 12 – ICM-42670-P

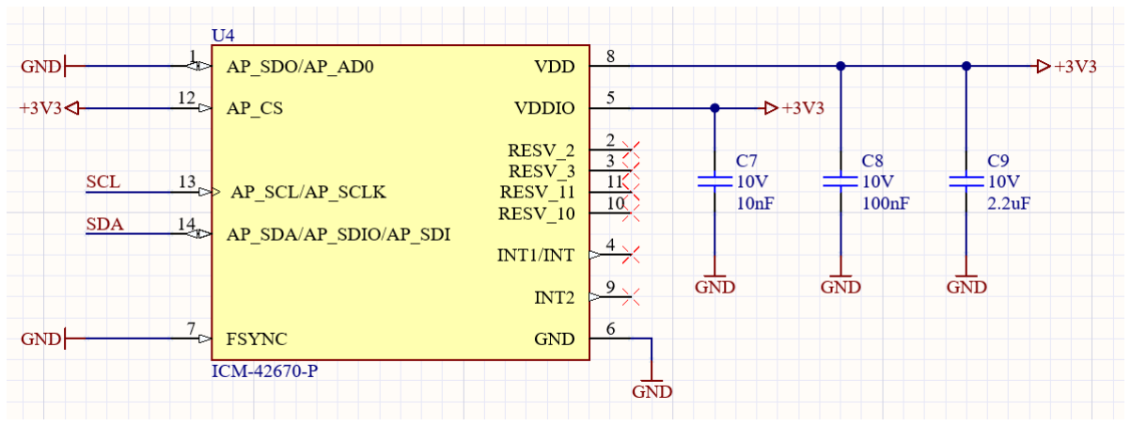
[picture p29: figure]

### 3.7 Module Bluetooth

Le module choisi, RN4678-V/100 de Microchip, possède deux technologie, le Bluetooth classique et le Bluetooth low-energy (BLE). Il est possible d’utiliser ce module en mode BLE, classique ou dual. Je l’ai sélectionné car il a été utilisé par plusieurs anciens élèves de l’ETML-ES et donc possède un driver connu et fonctionnel. Le DIP-switch SW1 à 3 entrées permet de modifier le mode opérationnel du module, c’est à dire qu’il est possible le mettre dans un mode fonctionnel, un mode écriture de l’EEPROM et test ou un mode écriture de la flash.

Le Baudrate par défaut du module est de 115200 Bauds d’où la fréquence du microcontroleur particulière, expliquée au point IMU. La LED va permettre d’afficher l’état du module :

- Standby
- Link Back
- Low Battery
- Inquiry
- Link

Figure 13 – RN4678-V/100

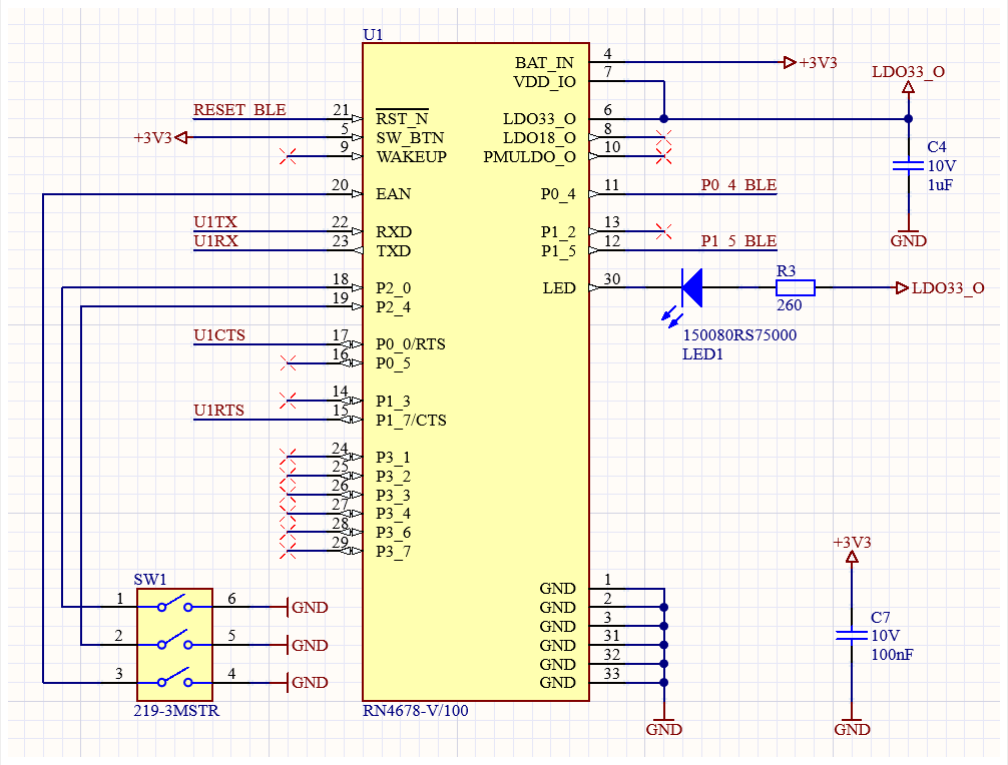
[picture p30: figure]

### 3.8 MCU

Le microcontroleur choisi est le PIC32MX130F064B-I/SS, il possède au total 28 Pins. J’ai choisi celui-la en fonction du nombre d’entrées sorties disppnibles mais également car il est en stock à l’ETML-ES. Ses principales fonctionnalités sont affichées dans le tableau ci-dessous.

PIC32MX130F064B | Valeur
Pins Program Memory (kB) Data Memory (kB) Remappable Pins Timers/Capture/Compare UART SPI/I2S External Interrupts Analog Comparators USB On-The-Go (OTG) I2C PMP 10-bit 1 Msps ADC (Channels) RTCC I/O Pins JTAG | 28 64+3 16 20 5/5/5 2 2 5 3 No 2 Yes 10 Yes 21 Yes

La fréquence du microcontroleur proviendra d’un oscillateur externe de 14.7456MHz afin d’obtenir un multiple du Baudrate du module Bluetooth qui est de 115200Bd de base. 14.7456MHz correspond à 128 x 115200Bd.

Figure 14 – Oscillateur de 14.7456MHz

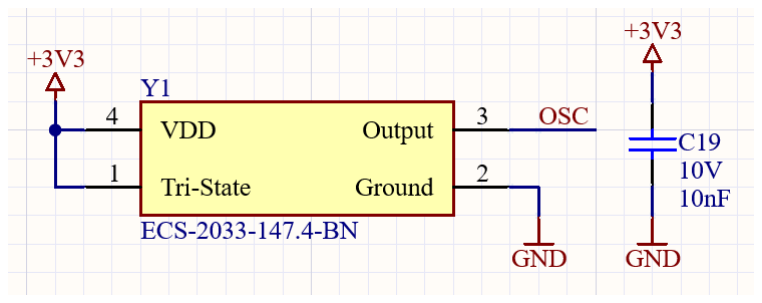
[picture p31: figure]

Les entrées et sorties du microcontrôleur ont été choisi à l’aide de l’utilitaire Harmony de MPLABX. Grâce à celui-ci il est plus simple de remapper les périphériques correctement.

Figure 15 – PIC32MX130F064B


Le circuit ce-dessous permet d’une part de programmer le microcontroleur à l’aide d’un ICD3 ou ICD4 mais également de reset manuellement le MCU dans le cas-ou il y a un problème lors de la programmation.

Figure 16 – Circuit de reset et connecteur programmeur


### 3.9 Alimentations

Le circuit d’alimentation sera composé de deux régulateurs de tension. La tension généré par la turbine entrera directement dans le premier régulateur de type Buck. La tension pouvant atteindre plus de 12V, j’ai choisi d’utiliser un régulateur Buck afin de ne pas dissiper toute la tension en chaleur. Sa sortie sera directement connectée à l’entrée du second régulateur. Celui-ci sera de type linéaire car la tension d’alimentation de la centrale inertielle ne doit pas être bruitée afin d’obtenir les mesures les plus précises possible. La diode Shottky permettra d’éviter qu’une tension n’aille dans la sortie du régulateur lorsque le module est alimenté par pile ou par USB et non pas par la turbine.

L’alimentation à découpage Wurth 173950536 est un composant intégrant l’alimentation et ses composant externes dans un même boîtier permettant ainsi de gagner de l’espace sur le PCB. La tension directe de la diode Schottky BAT45W-7-F est de 0.5V avec un courant d’environ 50mA ce qui baisse la tension entrant dans l’alimentation linéaire à 4.5V.
L’alimentation linéaire choisie est la TLV74333PDBVR du fabriquant Texas Instrument. Son entrée

Figure 17 – 173950536


sera connectée à un switch permettant de choisir soit la tension USB soit la tension des piles et comme expliqué précédemment à la sortie de l’alimentation Buck. Dans le cas ou le circuit est alimenté au sol par un câble USB, le switch fera office de bouton ON/OFF.

Figure 18 – TLV74333PDBVR


Le connecteur USB sera de type C car c’est de nos jours le plus commun pour les nouveaux appareils. Les résistances de 5.1k branchées à la masse servent à indiquer qu’il s’agit d’un USB 2.0, bien qu’il n’y ait pas de communication.

Figure 19 – Connecteur USB-C 2.0

### 3.10 Pull-up I2C


Les deux capteurs se trouvant sur le PCB utiliseront le bus I2C pour communiquer avec le MCU. Les deux lignes, SDA et SCL nécessitent l’ajout de pull-up afin de fonctionner correctement. Ces résistances peuvent avoir différentes valeurs en fonction de la vitesse de transmission. Dans ce produit, la communication ne nécessite pas un grand débit, d’ou le fait d’avoir mis des résistances de 10k afin de réduire la consommation.

Figure 20 – Pull-up I2C

## 4 Annexes

- Références
- Cahier des charges
- Schéma électrique

## Références

[1] Centrale à inertie. fr. Page Version ID : 192388914. Mars 2022. url : https://fr.wikipedia.org/w/index.php?title=Centrale_%C3%A0_inertie&oldid=192388914 (visité le 07/12/2022).
[2] maxon Motors as Generators. en-US. url : https://support.maxongroup.com/hc/en- us/ articles/360004496254-maxon-Motors-as-Generators (visité le 04/12/2022).
[3] Pression statique. fr. Page Version ID : 169954162. Avr. 2020. url : https://fr.wikipedia.org/w/index.php?title=Pression_statique&oldid=169954162 (visité le 03/12/2022).
[4] Pression totale. fr. Page Version ID : 198361997. Nov. 2022. url : https://fr.wikipedia.org/w/index.php?title=Pression_totale&oldid=198361997 (visité le 03/12/2022).
[5] Tube de Pitot. fr. Page Version ID : 198892898. Nov. 2022. url : https://fr.wikipedia.org/w/index.php?title=Tube_de_Pitot&oldid=198892898 (visité le 04/12/2022).

ECOLE SUPERIEURE | PROJ – SLO

1 : Produit; 2 : Appareil Android; 3 : Signaux BLE (Bluetooth Low Energy)

JMO – Nov 2022 | 2230_TubePitotDeporte-CDC_v1.0.0.docx | Page 1

# Projet ETML-ES - Cahier des charges

## A remplir par l'initiateur / porteur de projet

Entreprise/Client: | Département:
Demandé par (Prénom, Nom): | Date:

## A remplir par le gestionnaire de projet (étudiant)

Auteur (ETML-ES): | Meven Ricchieri | Filière: | SLO
| | Date: | 16.11.2022

# 1 But du projet

Le but du projet consiste à développer un système permettant de détecter l’angle d’incidence et la vitesse au décrochage d’un avion. La fixation de ce système doit être flexible afin de pouvoir l’installer sur différents types d’avions. L’emplacement de fixation ne doit pas se trouver dans le flux d’air provenant de l’hélice afin d’éviter que la mesure de vitesse ne soit faussée. Il doit également être miniaturisé au maximum afin de produire le minimum de trainée possible et de ne pas dépasser un poids de 500g. Les données acquises par les capteurs doivent être transmises de la partie déportée à un appareil Android se trouvant dans le cockpit de l’avion au travers une communication sans fil. L’appareil Android doit traiter et afficher les données reçues, si possible graphiquement (optionnel).

## 1.1 Schéma de principe

Figure 1 -

# Tube Pitot déporté

2230

ECOLE SUPERIEURE | PROJ – SLO


JMO – Nov 2022 | 2230_TubePitotDeporte-CDC_v1.0.0.docx | Page 2

# 2 Spécifications du projet

## 2.1 Schéma bloc

Figure 2 - Schéma bloc

## 2.1.1 Descriptions simple des blocs

- Générateur (turbine), l’idée est d’intégrer un générateur-turbine, montés à l’arrière du produit (voir Figure 3) afin de générer l’électricité nécessaire au système. Dans le cas où la réalisation mécanique de cela serait trop difficile, une batterie ou pile serait l’alternative.
- LED bleu, permettra d’indiquer l’état du système à un moment donné, elle devra être visible depuis

## l’intérieur du cockpit. Le comportement sera le suivant :

o LED éteinte, le système non alimenté.

## o Simple clignotement à une fréquence de 0.5Hz, le système n’est pas appairé à un

périphérique Bluetooth.

## o Double clignotement à une fréquence de 0.5Hz, le système est appairé à un périphérique

Bluetooth et fonctionnel.

ECOLE SUPERIEURE | PROJ – SLO


JMO – Nov 2022 | 2230_TubePitotDeporte-CDC_v1.0.0.docx | Page 3
- Connecteur USB, le connecteur permettra d’alimenter le système afin de le tester lorsqu’il est au sol.
- Tube Pitot, servira d’entrée d’air pour les capteurs de pression.
- Capteurs pression, ces capteurs liront les valeurs de la pression statique et totale pour ainsi calculer la vitesse air.
- Alimentation, l’alimentation transformera la tension provenant de la source d’énergie en une tension régulée et stable.
- IMU, la centrale inertielle servira à mesurer les vecteurs des vitesses angulaires et les accélérations.
- MCU, le microcontrôleur va être le cerveau du produit, il sera responsable de commander tous les autres composants.

## - Module BLE, le module Bluetooth Low Energy permettra d’établir une communication basse

consommation entre le produit et l’appareil Android. C’est par le biais de cette liaison que seront transmises toutes les données.
- Appareil Android, l’appareil recevra, traitera et affichera les données sur son écran. Il permettra également d’envoyer des commandes tels que la fréquence d’envoi ou d’autres paramètres. Les blocs seront décrits en détail dans la pré-étude.

## 2.2 Croquis du produit

L’intégration du système se fera dans un cylindre à l’arrière du tube Pitot comme représenté ci-dessous (vue en coupe). Dans le cas où la vitesse de rotation du générateur est trop élevée, l’ajout d’un carénage permettrait de diminuer la vitesse du flux d’air en augmentant la section de sortie par rapport à l’entrée. La fixation se réalisera à l’aide d’une boule style RAM-Mounts.

Figure 3 - Croquis du produit (vue en coupe)

# 3 Tâches à réaliser

- Pré-étude - Dimensionnement, design et réalisation du schéma - Commande des composant et du matériel - Réalisation du PCB - Design de l’assemblage mécanique avec fixations - Montage du PCB - Réalisation du software du MCU et de l’application Android - Impression 3D ou usinage de la partie mécanique - Mise en service et tests

ECOLE SUPERIEURE | PROJ – SLO


JMO – Nov 2022 | 2230_TubePitotDeporte-CDC_v1.0.0.docx | Page 4

# 4 Deadlines principales

- 16 novembre 2022 | : Début du projet
- 07 décembre 2022 | : Rendu de la pré-étude
- 14 décembre 2022 | : Présentation de la pré-étude
- 25 janvier 2023 | : Rendu du design
- 01 février 2023 | : Présentation du design
- 22 mars 2023 | : Rendu des fichiers de fabrication PCB
- 14 juin 2023 | : Rendu de toute la documentation finale
- 21 juin 2023 | : Présentation finale

## 4.1 Planning

Figure 4 - Planning

# 5 Livrables

- Les fichiers sources de CAO électronique et mécanique - Tout le nécessaire pour fabriquer un (1) exemplaire hardware : o Fichiers de fabrication (GERBER) o Liste de pièces avec références (BOM) o Implantation des composants o Dessins mécaniques - Les fichiers sources de programmation du microcontrôleur (.c/.h) - Tout le nécessaire pour programmer les microcontrôleurs (.hex)

- Les fichiers sources de programmation Android.
- Tout le nécessaire à l’installation de programmes sur Android.

## - Un mode d’emploi du produit - Une estimation des coûts du projet

- Un rapport contenant toutes les informations du design du produit.

## - Un prototype monté et fonctionnel - Une application Android permettant d’afficher les données : o Affichage numérique o Affichage graphique (optionnel)


Générateur, connecteur et gestion vitesse rotation

Support et connecteur piles rechargeables

Connecteur ICSP et bouton reset

Capteur de pressions différentielles

Avenue Recordon 1
1004 Lausanne
Switzerland
Chemin : P:\School\PROJ\2230_TubePitotDeporte\hard\PCB_Project\2230_TubePitotDeporte_Schematic_v1.0.0.SchDoc

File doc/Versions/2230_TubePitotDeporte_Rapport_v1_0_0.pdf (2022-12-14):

# Tube Pitot déporté

Détection de l’angle d’incidence au décrochage d’un avion par mesure de la vitesse et des accélérations

Meven Ricchieri
2022 - 2023
Numéro de projet | : | 2230
Responsable | : | M. Juan José Moreno
Mandataire | : | M. Vincent Seguin (pour AMPA)

2230_TubePitotDeporte-Rapport_v1.0.0

## Table des matières

1 Cahier des charges | 2
2 Pré-étude | 2
3 Annexes | 9

## 1 Cahier des charges

Le but du projet consiste à développer un système permettant de détecter l’angle d’incidence et la vitesse au décrochage d’un avion. La fixation de ce système doit être flexible afin de pouvoir l’installer sur différents types d’avions. L’emplacement de fixation ne doit pas se trouver dans le flux d’air provenant de l’hélice afin d’éviter que la mesure de vitesse ne soit faussée. Il doit également être miniaturisé au maximum afin de produire le minimum de traînée possible et de ne pas dépasser un poids de 500g. Les données acquises par les capteurs doivent être transmises de la partie déportée à un appareil Android se trouvant dans le cockpit de l’avion au travers une communication sans fil. L’appareil Android doit traiter et afficher les données reçues, si possible graphiquement (optionnel).

Le cahier des charges complet se trouve en annexes.

## 2 Pré-étude

### 2.1 Contexte

Cette pré-étude consiste à mener des recherches qui conduirons à une décision de lancer ou non le projet. Cette décision va reposer sur les difficultés de réalisation électrique, mécanique et software. Elle va aussi permettre d’imaginer et de comparer les différentes manières de réaliser les tâches et ainsi choisir la meilleure.

### 2.2 Schéma de principe


Figure 1 – Schéma de principe

### 2.3 Schéma bloc détaillé


Figure 2 – Schéma bloc détaillé

### 2.4 Descriptions des blocs détaillées

### 2.4.1 Bloc Générateur (turbine)

L’intérêt d’utiliser un générateur comme source d’énergie permet de simplifier l’utilisation du système, il n’y aura aucune maintenance à effectuer ou de batterie à charger. L’énergie cinétique de l’air en mouvement, par rapport à l’avion, vas être captée par les aubes de la turbine axée à un générateur, ce qui va produire une tension. Le système va se mettre en marche une fois que l’axe du générateurturbine aura atteint une certaine vitesse de rotation. Plus la vitesse sera grande, plus la tension générée sera élevée. Un simple moteur DC, va permettre de transformer cette énergie mécanique en énergie électrique. Il est possible d’utiliser d’autres technologies comme les moteurs brushless, qui ont un rendement bien meilleur, mais cela complexifie le circuit et augmente le prix. Dans ce projet, le rendement n’est pas primordial car le système ne consommera que très peu d’énergie.

Ut(V ) = n
kn
− Rmot ∗ IL [2] | (1)

où :
Ut | = | Tension aux bornes du moteur DC (V)
kn | = | Constante de vitesse du moteur DC (rpm/V)
Rmot | = | Résistance aux bornes du moteur DC (Ω)
n | = | Vitesse moteur DC (rpm)
IL | = | Courant de charge (I)

Puisque la valeur de la tension générée est dépendante de la vitesse air de l’avion, celle-ci ne sera jamais stable. Il faudra donc la transformer et la réguler avant de la transmettre aux composants électroniques, ce à quoi le bloc "Alimentation" sera destiné.

N’ayant pas de grandes connaissances dans le dimensionnement et le design de générateur-turbines, des recherches plus poussées seront nécessaires afin de rendre le système performant. Pour me faire une première idée, j’ai dessiné et imprimé une première turbine composée de 13 aubes puis j’ai effectué quelques tests. A l’aide d’un moteur DC, j’ai réussi à générer une tension d’environ 3V à une vitesse de 80km/h.


Figure 3 – Turbine de test N°1

### 2.4.2 Bloc Capteur de pression

Le système sera équipé d’un capteur de pression différentiel qui permettra de mesurer la différence entre la pression statique et la pression totale. "La pression statique, dans un fluide en mouvement, est la pression que mesure un capteur qui se déplace à la même vitesse que le fluide" [3]. "La pression totale dans un fluide (eau, air, etc.) est la somme de la pression statique, de la pression dynamique, et de la densité volumique d’énergie potentielle de gravité" [4]. Grâce aux valeurs ainsi mesurées, il sera possible de calculer la vélocité du fluide, ce qui correspondra à la vitesse air de l’avion. Pour des vitesses inférieures à Mach 0.3 (200 nœuds), l’effet de compressibilité du fluide peut être négligé [5].

v(m/s) = s
2 ∗ (pt − ps)
ρ
[5] (2)

où :
v | = | Vélocité du fluide (m/s)
pt | = | Pression totale (Pa)
ps | = | Pression statique (Pa)
ρ | = | Masse volumique du fluide (kg/m³
)

### 2.4.3 Bloc Tube Pitot

Comme expliqué au point précédent, la vitesse se calcule grâce à la pression statique et totale, pour que le capteur différentiel ait accès à ces deux pressions, il faut ajouter deux entrées d’air. Ces entrées doivent être placées correctement car dans le cas contraire, la vitesse calculée ne sera pas correcte. L’entrée de la pression statique doit être perpendiculaire à l’écoulement local du fluide (non perturbé) alors que celle de la pression totale doit être parallèle à ce flux. Il existe 3 tubes différents, le premier, appelé tube Pitot simple, est simplement un tube perforé en son centre faisant office d’entrée d’air pour la pression totale. Le second, appelé sonde statique, est perforé latéralement permettant l’entrée d’air pour la pression statique. Le troisième est une combinaison des deux premiers, il dispose d’une entrée pour la pression totale et d’une autre pour la pression statique. L’idéal serait d’utiliser ce dernier car il simplifierait l’implémentation mécanique du système. Les deux sorties du tube seraient reliées au capteur différentiel par des tuyaux. Dans le cas ou un tube Pitot simple serait utilisé, il serait nécessaire de perforer le boîtier du produit afin d’avoir accès à la pression statique. La décision du type de tube sera effectué lors du design mécanique car il n’influence aucunement la conception électronique.

Figure 4 – Types de tubes Pitot


### 2.4.4 Bloc IMU

La centrale inertielle comportera 6 capteurs, 3 gyromètres et 3 accéléromètres. "Les gyromètres mesurent les trois composantes du vecteur vitesse angulaire (vitesses de variation des angles de roulis, de tangage et de lacet. Les accéléromètres mesurent les trois composantes du vecteur force spécifique. La force spécifique est la somme des forces extérieures autres que gravitationnelles divisée par la masse" [1]. C’est grâce à ses capteurs qu’il sera possible de détecter le moment où l’avion commence à décrocher. La plupart de ces IMUs ont également un capteur de température intégré, la mesure de cette grandeur peut être intéressante puisqu’elle a une influence sur la valeur de la pression.


Figure 5 – Données mesurés par l’IMU

### 2.4.5 Bloc Connecteur USB

Étant donné que le système n’aura pas de source d’énergie interne, un connecteur USB-C sera implémenté afin de pouvoir tester la communication ainsi que les capteurs, en amont du vol. Il permettra également d’alimenter le système lors de son installation sur l’avion, car il devra être positionné correctement à l’horizontale pour que les mesures soient fiables.

### 2.4.6 Bloc Module BLE

Le transfert de données entre le produit et l’appareil Android, se fera au travers d’une communication sans fil Bluetooth Low Energy (BLE). Cette variante de Bluetooth permet de réduire significativement sa consommation par rapport au mode normal. Il sera tout de même possible qu’un module permettant de choisir le mode de fonctionnement soit implémenté. Les données transmises du produit à l’appareil Android seront principalement les valeurs lues par les capteurs alors que celle provenant de l’appareil seront plutôt des commandes ou réglages.

### 2.4.7 Bloc LED bleu

Comme énoncé dans le CDC, la LED bleue va permettre d’indiquer l’état du système. La LED éteinte va signifier que le système n’est pas alimenté. Un clignotement toute les 2 secondes correspondra au système alimenté mais non appairé à un périphérique Bluetooth et finalement, 2 clignotements toute les 2 secondes correspondra à l’état fonctionnel, appairé et transmettant les données. La LED devra être visible de jour donc son emplacement et son intensité lumineuse devront être correctement défini.

### 2.4.8 Bloc MCU

Le microcontrôleur sera obligatoirement un modèle 32Bit du fabriquant Microchip. Il va faire le lien entre tous les périphériques implémentés, c’est à dire les composants d’entrées, IMU et capteur de pression et ceux de sortie, module BLE et LED. Selon les recherches effectués précédemment, le microcontrôleur devra au minimum contenir,

— Un module UART pour la communication avec le module Bluetooth
— Un module I2C pour la communication avec l’IMU
— Une PIN GPIO pour le contrôle de la LED

### 2.4.9 Bloc Alimentation

Puisque la grande majorité des composants nécessaires, tel que le PIC ou les capteurs, fonctionnent avec une tensions de 3.3V, il faudra donc que la sortie de ce bloc soit proche de cette valeur. Le générateur va produire une tension bien supérieur à 3.3V, donc la meilleure option est d’utiliser un convertisseur Buck afin de l’abaisser. Il permettra d’avoir un bien meilleur rendement qu’un régulateur linéaire et donc limiter la consommation.

### 2.4.10 Bloc Appareil Android

Toutes les données obtenues au travers de la communication sans fil seront traitées et affichées sur l’écran de l’appareil. Ces données seront affichées sous forme numérique et dans l’idéal, sous forme graphiques, mais cela reste optionnel. L’application permettra d’envoyer certaines commandes au produit en appuyant sur les différents boutons qui seront affichés. Il sera aussi possible d’ajouter une valeur d’offset aux mesures pour compenser une éventuelle erreur.

### 2.5 Design mécanique

Comme expliqué dans le cahier des charges, l’idée est d’adapter tout le système pour qu’il puisse se trouver dans un cylindre à l’arrière du tube Pitot. Le boîtier et les autres parties mécaniques seront imprimé en une matière plastique selon la disponibilité de matériaux de l’école. L’idéal serait d’utiliser de l’acrylonitrile butadiène styrène (ABS) car ses caractéristiques mécaniques sont bien supérieures à l’acide polylactique (PLA). La grosse difficulté va être de miniaturiser le design du PCB afin de rendre la section du tube la plus mince possible. Le système de fixation sera réalisé grâce à une boule style RAM-Mounts vissé au boîtier.


Figure 6 – Premier croquis du design mécanique

### 2.6 Estimation du prix

L’estimation du prix est actuellement difficile car certains choix doivent encore êtres pris et la disponibilité des composants peut avoir une influence, j’ai donc mis un plage de prix.

— Générateur (moteur DC) : 5 - 50.-
— Turbine (ABS) : 0.5 - 1.-
— Capteur différentiel : 30 - 70.-
— Tube Pitot : 0 - 30.-
— Centrale inertielle : 5 - 12.-— Connecteur USB-C : 1 - 3.-— Module Bluetooth : 5 - 15.-— LED : 0.5 - 3.-
— MCU : 1 - 3.-
— Convertisseur Buck : 3 - 8.-
— Boîtier (ABS) : 1 - 2.-
— Boule RAM-Mounts : 15 - 25.-
— PCB : 50 - 75.-

Le prix devrait se situer entre 126.- et 396.-

### 2.7 Faisabilité du projet

D’après les informations trouvées, le projet est totalement réalisable. Il y aura sans doutes quelques difficultés au niveau du dimensionnement de la partie turbine-générateur.

## 3 Annexes

- Cahier des charges

## Références

[1] Centrale à inertie. fr. Page Version ID : 192388914. Mars 2022. url : https://fr.wikipedia.org/w/index.php?title=Centrale_%C3%A0_inertie&oldid=192388914 (visité le 07/12/2022).
[2] maxon Motors as Generators. en-US. url : https://support.maxongroup.com/hc/en- us/ articles/360004496254-maxon-Motors-as-Generators (visité le 04/12/2022).
[3] Pression statique. fr. Page Version ID : 169954162. Avr. 2020. url : https://fr.wikipedia.org/w/index.php?title=Pression_statique&oldid=169954162 (visité le 03/12/2022).
[4] Pression totale. fr. Page Version ID : 198361997. Nov. 2022. url : https://fr.wikipedia.org/w/index.php?title=Pression_totale&oldid=198361997 (visité le 03/12/2022).
[5] Tube de Pitot. fr. Page Version ID : 198892898. Nov. 2022. url : https://fr.wikipedia.org/w/index.php?title=Tube_de_Pitot&oldid=198892898 (visité le 04/12/2022).

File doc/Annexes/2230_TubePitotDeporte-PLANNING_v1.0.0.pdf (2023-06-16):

No semaine de travail | 1 | 2 | 3 | 4 | 5 | 6 | V | V | 7 | 8 | 9 | 10 | 11 | V | 12 | 13 | 14 | 15 | 16 | 17 | 18 | V | V | 19 | 20 | 21 | 22 | 23 | 24 | 25 | 26 | 27 | 28
No semaine | 46 | 47 | 48 | 49 | 50 | 51 | 52 | 1 | 2 | 3 | 4 | 5 | 6 | 7 | 8 | 9 | 10 | 11 | 12 | 13 | 14 | 15 | 16 | 17 | 18 | 19 | 20 | 21 | 22 | 23 | 24 | 25 | 26

Date
Cahier des charges | O | O | N
Pré‐étude | O | O | O | O | O
Dimensionnement + design + schéma | | | | N | N | O | | | O | O | O | O
Design du PCB | | | | | | | | | | N | N | N | O | | O | O | O | O | O
Design de des parties mécaniques | | | | | | | | | | N | N | N | N | | O | O | O | O | O | N | N
Montage PCB | | | | | | | | | | | | | | | | | | | | N | O | | | O
Impression ou usinage mécanique | | | | | | | | | | | | | | | | | N | N | N | N | N
Réalisation des softwares | | | | | | | | | | | | | | | | | | | N | N | O | | | O | O | O | O | O | O | O | O
Mise en service et tests | | | | | | | | | | | | | | | | | | | | | | | | N | N | O | O | O | O | O | O
Préparation présentation | | | | | | | | | | | | | | | | | | | | | | | | | | | | | | O | O
Présentation finale
Rédaction rapport | O | O | O | O | O | O | | | O | O | O | O | N | | N | N | N | N | N | N | N | | | N | N | N | N | O | O | O | O
Finalisation/corrections/documentation | | | | | | | | | | | | | | | | | | | | | | | | | | | | | | N | N

16.11.2022

23.11.2022

30.11.2022

07.12.2022

14.12.2022

21.12.2022

28.12.2022

04.01.2023

11.01.2023

18.01.2023

25.01.2023

01.02.2023

08.02.2023

15.02.2023

22.02.2023

01.03.2023

08.03.2023

15.03.2023

22.03.2023

29.03.2023

05.04.2023

12.04.2023

19.04.2023

26.04.2023

03.05.2023

10.05.2023

17.05.2023

24.05.2023

31.05.2023

07.06.2023

14.06.2023

21.06.2023

28.06.2023

Vacances | O | O
Remise de documents | N | N
Présentation

Plannification correcte
Plannification incorrecte

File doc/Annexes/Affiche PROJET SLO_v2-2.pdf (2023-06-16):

### Meven Ricchieri

TECHNICIEN-NE ES EN GÉNIE ÉLECTRIQUE / 2022-2023


## www.etml-es.ch


rue de Sébeillon 12, 1004 Lausanne | ETML

2230 Tube Pitot Déporté

Le but du projet consiste à développer un système permettant de détecter l’angle d’incidence et là vitesse au décrochage d’un avion. La fixation de ce système doit être flexible afin de pouvoir l’installer sur différents types d’avions. L’emplacement de fixation ne doit pas se trouver dans le flux d’air provenant de l’hélice afin d’éviter que la mesure de vitesse ne soit faussée. Il doit également être miniaturisé au maximum afin de produire le minimum de traînée possible et de ne pas dépasser un poids de 500g. Les données acquises par les capteurs doivent être transmises de la partie déportée à un appareil Android se trouvant dans le cockpit de l’avion au travers une communication sans fil. L’appareil Android doit traiter et afficher les données reçues, si possible graphiquement (optionnel).

La réalisation de ce projet a été une expérience inestimable qui m'a permis d'élargir mes compétences en travaillant avec des composants variés que je n'avais jamais manipulés auparavant. Cette opportunité a renforcé ma détermination et mon dévouement envers le projet, car il incarnait une occasion unique de contribuer à un domaine qui suscite en moi une profonde inspiration et fascination : l'aéronautique. Travailler sur ce projet a été une expérience incroyablement gratifiante et motivante, comblant mes aspirations en tant qu'enthousiaste passionné d'aéronautique.

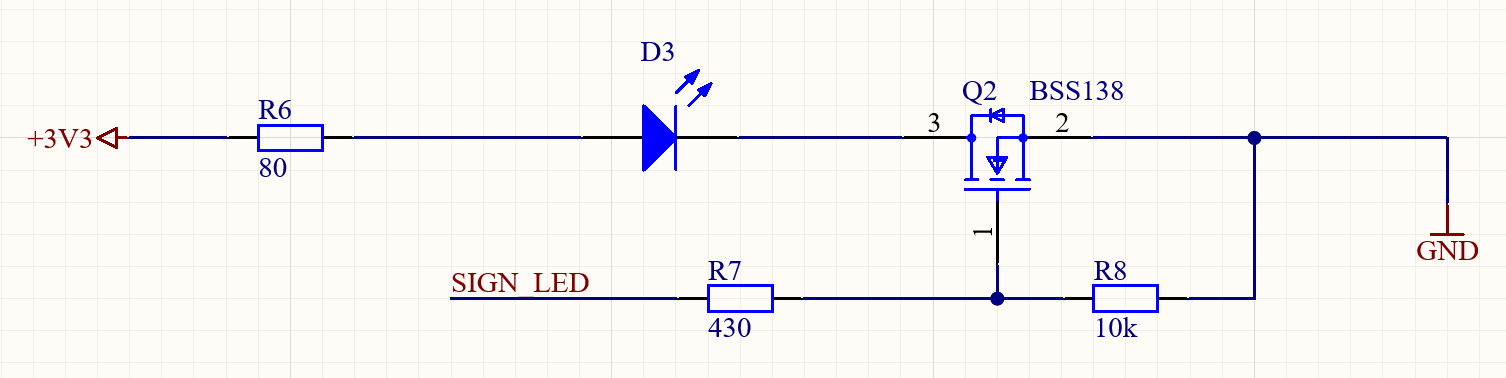
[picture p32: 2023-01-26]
doc/images/DesignElec/LED_SCH.PNG

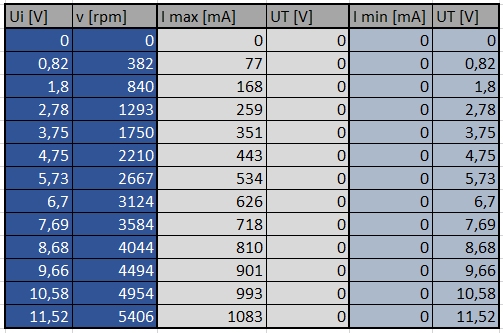
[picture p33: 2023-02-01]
doc/images/DesignElec/MoteurTableau.PNG

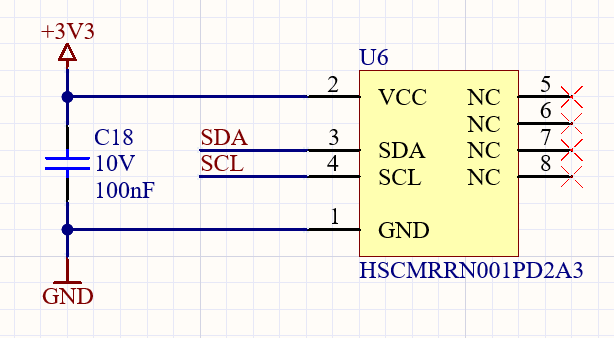
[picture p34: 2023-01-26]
doc/images/DesignElec/CapteurPressionsDiff_SCH.PNG

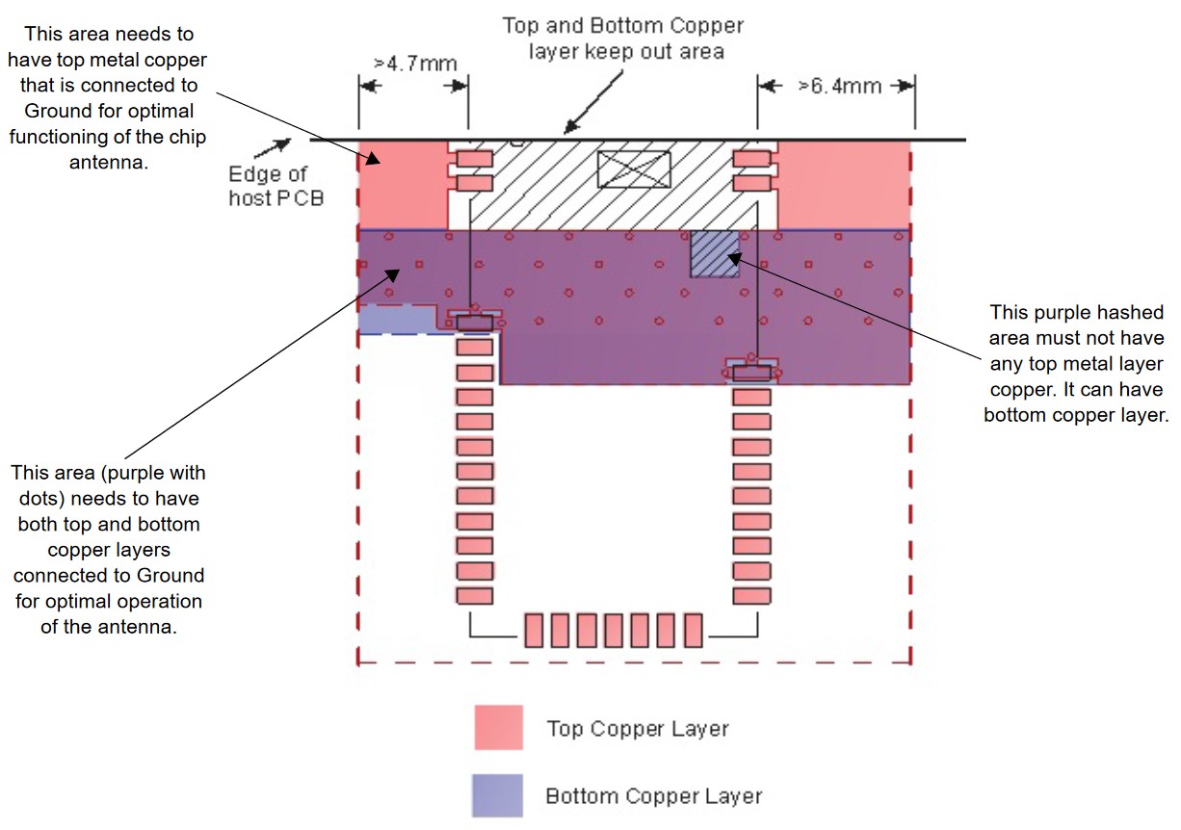
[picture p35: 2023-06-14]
doc/images/DesignMecEtPCB/BT_ModuleFootprint.jpg

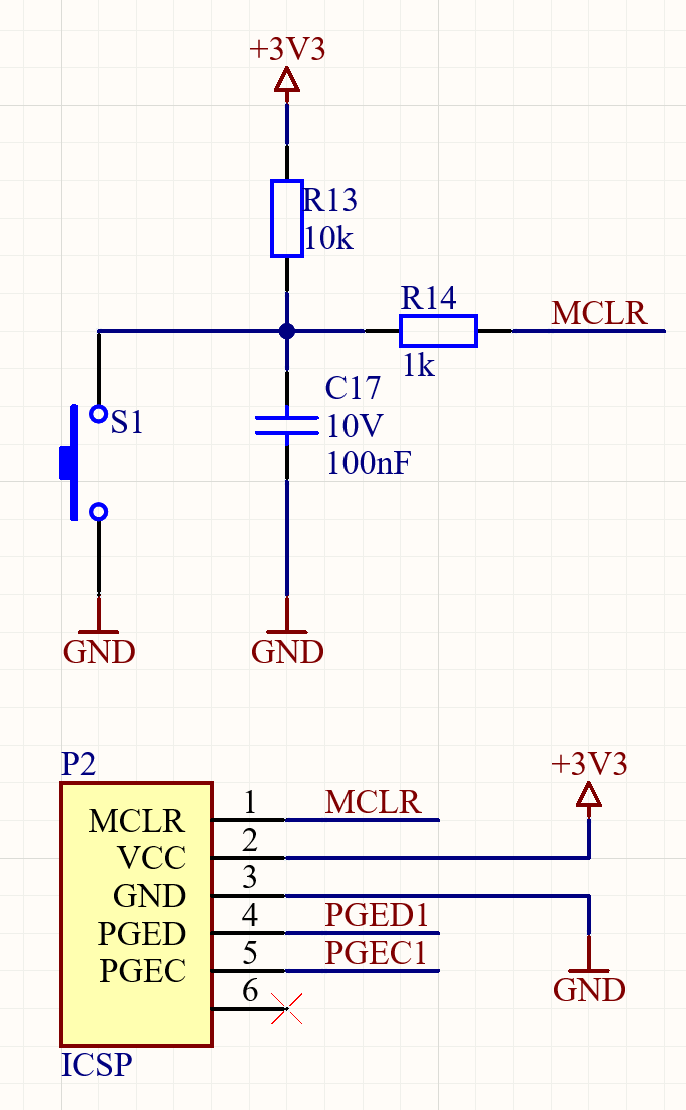
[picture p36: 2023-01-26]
doc/images/DesignElec/Prog-Reset_SCH.png

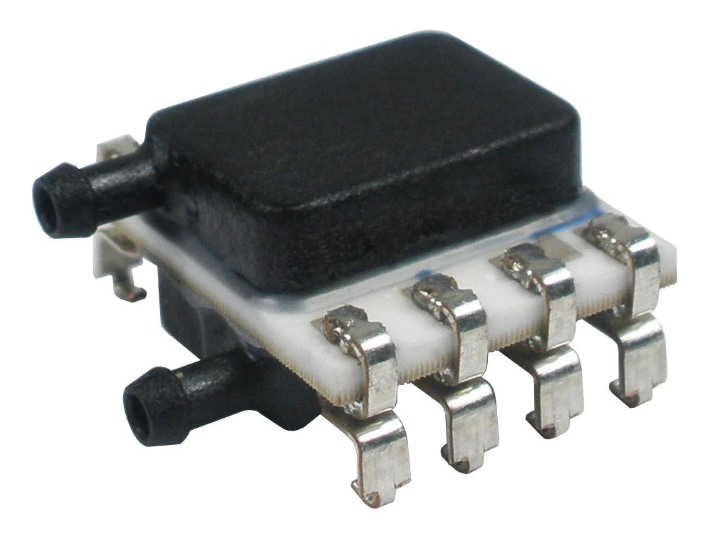
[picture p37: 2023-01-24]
doc/images/DesignElec/CapteurPressionsDiff_IMG.PNG

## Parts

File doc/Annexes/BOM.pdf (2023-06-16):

UJC‐HP‐3‐SMT‐TR | USBC connector | Digi‐Key | P1 | No | Not managed | 1 CUI Devices | UJC‐HP‐3‐SMT‐TR | Volume Production2223‐UJC‐HP‐3‐SMT‐CT‐ND | 1,16 | 1,16 Clear
2 TLV74333PDBVR | IC REG LINEAR 3.3V 300MA SOT23‐5 | Mouser | U3 | No CMP‐04917‐000051‐1 New From Up to date 1 Texas Instruments | TLV74333PDBVR | Volume Production595‐TLV74333PDBVR | 0,31 | 0,31 Clear
3 SM02B‐GHS‐TB(LF)(SN) | CONN HEADER SMD R/A 2POS 1.25MM | Digi‐Key | J1 | No CMP‐2000‐07076‐2 | Released Up to date 1 JST | SM02B‐GHS‐TB(LF)(SN) | Unknown | 455‐1564‐1‐ND | 0,45 | 0,45 Clear
4 S2B‐PH‐SM4‐TB(LF)(SN) | Male Header, Pitch 2 mm, 1 x 2 Position, Height 5.5 mm, ‐25 to 85 degC, RoHS, Tape and ReeDigikey | P3 | No CMP‐1755‐00001‐1 | Released Up to date 1 JST Sales America Inc. | S2B‐PH‐SM4‐TB(LF)(SN) | Manual Solution | 455‐1749‐2‐ND | 0,53702 0,53702 Clear
5 RN4678‐V/100 | Bluetooth Bluetooth v5.0 Transceiver Module 2.4GHz Integrated, Chip Surface Mount | Digi‐Key | U1 | No | Not managed | 1 Microchip | RN4678‐V/RM100 | Volume ProductionRN4678‐V/RM100‐ND | 13,82 | 13,82 Clear
RAM‐Mount Diamound | RAM‐Mount fixation | | | Yes | Not managed | 1 | | | | | Fatal error
16 PIC32MX130F064B‐I/SS | PIC32MX130F064B‐I/SS | Digi‐Key | U5 | Yes | Not managed | 1 Microchip | PIC32MX130F064B‐I/SS | Volume ProductionPIC32MX130F064B‐I/SS‐ND | 3,54 | 3,54 Clear
LTL‐4223 | THT LED RED | Digi‐Key | No | Not managed | 1 Vishay Lite‐On | LTL‐4223 | Volume Production160‐1127‐ND | 0,36 | 0,36 Clear
Jeti Tube Pitot DUPLEX | Tube Pitot | | | Yes | Not managed | 1 | | | | | Fatal error
ICSP | Prog | Digi‐Key | P2 | Yes | Not managed | 1 Adam Equipment | PH1‐05‐UA | Unknown | 2057‐PH1‐05‐UA‐ND | 0,1 | 0,1 Clear
19 ICM‐42670‐P | 6 axis IMU | Mouser | U4 | No | Not managed | 1 TDK | ICM‐42670‐P | Unknown | 410‐ICM‐42670‐P | 5,97 | 5,97 Clear
GHR‐03V‐S | 1.25mm JST female connector 3P | Conrad | No | Not managed | 3 JST | GHR‐03V‐S | Manual Solution | 1426141 0,11868 0,47471 Clear
GHR‐02V‐S | 1.25mm JST female connector 2P | Digi‐Key | | No | Not managed | 2 JST | GHR‐02V‐S | Unknown | 455‐1592‐ND | 0,13 | 0,26 Clear
20 FSM2JSMAA | SWITCH TACTILE SPST‐NO 0.05A 24V | Mouser | SW2 | Yes CMP‐03402‐000003‐1 New From Up to date 1 TE Connectivity | FSM2JSMAA | Volume Production506‐2‐1437565‐8 | 0,23 | 0,23 Clear
ECS‐2033‐147.4‐BN | ECS‐2033‐147.4‐BN 14.7456 MHz Oscillator | Digi‐Key | Y1 | No | Not managed | 1 ECS International | ECS‐2033‐147.4‐BN | Volume ProductionXC1429CT‐ND | 1,19 | 1,19 Clear
22 DMG3414U‐7 | MOSFET N‐CH 20V 4.2A SOT23 | Digi‐Key | Q1 | No CMP‐12801‐000101‐1 New From Up to date 1 Diodes | DMG3414U‐7 | Volume ProductionDMG3414U‐7DICT‐ND | 0,46 | 0,46 Clear
23 BSS138 | MOSFET N‐CH 50V 220MA SOT‐23 | Digikey | Q2 | No CMP‐07173‐000101‐1 New From Up to date 1 ANBON SEMICONDUCTOR (INT'L) LIMITED BSS138 | Manual Solution | 4530‐BSS138CT‐ND | 0,17491 0,17491 Clear
25 BM03B‐GHS‐TBT(LF)(SN)(N) CONN HEADER SMD 3POS 1.25MM | Digi‐Key | J2, J3 | No CMP‐17439‐000058‐1 New From Up to date 2 JST | BM03B‐GHS‐TBT(LF)(SN)(N) Unknown | 455‐1579‐1‐ND | 0,47 | 0,94 Clear
BH24AAW | Support Piles AA | Digi‐Key | | No | Not managed | 1 Memory Protection Devices | BH24AAW | Unknown | BH24AAW‐ND | 2 | 2 Clear
26 BAT46W‐7‐F | Zener Diode | Mouser | D1, D2 | No | Not managed | 2 Diodes | BAT46W‐7‐F | Volume Production621‐BAT46W‐7‐F | 0,41 | 0,82 Clear
27 B260‐13‐F | Zener Diode | Arrow ElectronicsD4 | No | Not managed | 1 Diodes | B260‐13‐F | Volume ProductionB260‐13‐F | 0,2809 0,2809 Clear
AGHGH28K102 | JST 1.25mm cable | Digi‐Key | | No | Not managed | 10 JST | AGHGH28K102 | Unknown | 455‐4360‐ND | 0,382 | 3,82 Clear
AGHGH28k203 | | Digi‐Key | | No | Not managed | 0 JST | AGHGH28K203 | Unknown | 455‐4361‐ND | 0 | 0 Warning
28 | 173950536 Buck 5V | Digikey | U2 | Yes | Not managed | 1 Würth Elektronik | | 173950536 Manual Solution | 732‐173950536‐ND | 6,14 | 6,14 Clear
29 150080RS75000 | SMD mono‐color Chip LED, WL‐SMCW, Red | Mouser | LED1 | No CMP‐1426‐00011‐1 | Released Up to date 1 Wurth Electronics | 150080RS75000 | Volume Production710‐150080RS75000 | 0,19 | 0,19 Clear
30 | 5019 Test Point, 1 Position SMD, RoHS, Tape and Reel | Mouser | TP1, TP2, TP3, TP4, TP5, TP6, TP7, TP8, TP9, TP10 No CMP‐1672‐00008‐1 | Released Up to date 10 Keystone Electronics | 5019 Volume Production534‐5019 | 0,33 | 3,3 Clear
2254‐440x219H‐ND | | Digi‐Key | | No | Not managed | 10 Tri‐Star | 440X219H | Unknown | 2254‐440X219H‐ND | 0,144 | 1,44 Clear
785‐HSCMRRN001PD2A3 Air sensor | Mouser | U6 | Yes | Not managed | 1 Honeywell Sensing & Control | HSCMRRN001PD2A3 | Volume Production785‐HSCMRRN001PD2A3 | 68,91 | 68,91 Clear
500SSP1S1M1QEB | Switch ON/OFF | Digi‐Key | | No | Not managed | 1 E‐Switch | 500SSP1S1M1QEB | Unknown | EG2476‐ND | 3,02 | 3,02 Fatal error
440X219H | Insert M2.5 | Digi‐Key | | No | Not managed | 6 Tri‐Star | 440X219H | Unknown | 2254‐440X219H‐ND | 0,172 | 1,03 Clear
430R | Resistor | Digi‐Key | R4, R7 | Yes | Not managed | 2 Yageo | RC0805JR‐07430RL | Volume Production311‐430ARCT‐ND | 0,1 | 0,2 Clear
428.351 | Connecteur JST 1.25 mm | | | No | Not managed | 0 | | | | | Fatal error
270R | Resistor | Digi‐Key | R3 | Yes | Not managed | 1 Yageo | RC0805JR‐07270RL | Volume Production311‐270ARCT‐ND | 0,1 | 0,1 Clear
| 261 2mm JST female connector 2P | Mouser | | No | Not managed | 1 Adafruit Industries | | 261 Unknown | 485‐261 | 0,75 | 0,75 Clear
32 219‐3MSTR | SWITCH SLIDE DIP SPST 100MA 20V | Digi‐Key | SW1 | No CMP‐07018‐000004‐1 New From Up to date 1 CTS | 219‐3MSTR | Volume ProductionCT3094CT‐ND | 0,69 | 0,69 Clear
82R | Resistor | Digi‐Key | R6 | Yes | Not managed | 1 Yageo | RC0805JR‐0782RL | Volume Production311‐82ARCT‐ND | 0,1 | 0,1 Clear
33 25V | Capacitor | Digi‐Key | C1 | Yes | Not managed | 1 Samsung | CL21A106KAYNNNE | Volume Production1276‐2891‐1‐ND | 0,18 | 0,18 Warning
34 25V | Capacitor | Mouser | C2 | Yes | Not managed | 1 Samsung | CL21B104KBCNNNC | Volume Production187‐CL21B104KBCNNNC | 0,1 | 0,1 Warning
35 10V | Capacitor | Digi‐Key | C3, C13, C16 | Yes | Not managed | 3 Samsung | CL21A106KPFNNNE | Volume Production1276‐1052‐6‐ND | 0,11 | 0,33 Warning
36 10V | Capacitor | Digi‐Key | C4, C5 | No | Not managed | 2 Kyocera AVX | 0805YC105KAT2A | Volume Production478‐5034‐1‐ND | 0,18 | 0,36 Fatal error
37 10V | Capacitor | Digi‐Key | C7, C9, C11, C12, C17, C18 | Yes | Not managed | 6 Samsung | CL21B104KBCNNNC | Volume Production1276‐1003‐1‐ND | 0,044 | 0,44 Warning
38 10V | Capacitor | Digi‐Key | C8, C19 | Yes | Not managed | 2 Samsung | CL21B103KBANNNC | Volume Production1276‐1015‐1‐ND | 0,1 | 0,2 Clear
39 10V | Capacitor | Digi‐Key | C10 | No | Not managed | 1 Samsung | CL21B225KAFNFNE | Volume Production1276‐2953‐1‐ND | 0,2 | 0,2 Clear
40 10v | Capacitor | Digi‐Key | C6 | No | Not managed | 1 Samsung | CL21B105KAFNNNE | Volume Production1276‐1066‐1‐ND | 0,1 | 0,1 Warning
10k | Resistor | | R11, R12 | Yes | Not managed | 2 | | | | | Fatal error
10k | Resistor | Mouser | R1, R5, R8, R13 | Yes | Not managed | 4 Yageo | RC0805JR‐0710KL | Volume Production603‐RC0805JR‐0710KL | 0,021 | 0,21 Clear
5k1 | Resistor | Digi‐Key | R9, R10, R17, R18 | Yes | Not managed | 4 Yageo | RC0805JR‐075K1L | Volume Production311‐5.1KARCT‐ND | 0,022 | 0,22 Clear
3k | Resistor | Digi‐Key | R15 | Yes | Not managed | 1 Yageo | RC0805FR‐103KL | Volume Production13‐RC0805FR‐103KLCT‐ND | 0,1 | 0,1 Clear
2k | Resistor | Digi‐Key | R2 | Yes | Not managed | 1 Stackpole Electronics | RNCP0805FTD2K00 | Volume ProductionRNCP0805FTD2K00CT‐ND | 0,1 | 0,1 Clear
1k | Resistor | Digi‐Key | R14 | Yes | Not managed | 1 Stackpole Electronics | RNCP0805FTD1K00 | Volume ProductionRNCP0805FTD1K00CT‐ND | 0,1 | 0,1 Clear
0R | Resistor | Digi‐Key | R16 | Yes | Not managed | 1 Stackpole Electronics | RMCF0805ZT0R00 | Volume ProductionRMCF0805ZT0R00CT‐ND | 0,1 | 0,1 Clear

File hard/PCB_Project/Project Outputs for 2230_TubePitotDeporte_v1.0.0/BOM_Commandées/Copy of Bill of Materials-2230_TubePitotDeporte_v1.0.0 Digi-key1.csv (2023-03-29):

1 | 455-1564-1-ND | CONN HEADER SMD R/A 2POS 1.25MM | 0.4171 | No | Digi-Key
3 | 1276-1066-1-ND | Capacitor | 0.09269 | No | Digi-Key
3 | 1276-2953-1-ND | Capacitor | 0.18538 | No | Digi-Key
1 | 2223-UJC-HP-3-SMT-CT-ND | USBC connector | 1.08 | No | Digi-Key
2 | CT3094CT-ND | SWITCH SLIDE DIP SPST 100MA 20V | 0.64882 | No | Digi-Key
2 | DMG3414U-7DICT-ND | MOSFET N-CH 20V 4.2A SOT23 | 0.4449 | No | Digi-Key
1 | EG2476-ND | Switch ON/OFF | 2.8 | No | Digi-Key
1 | RN4678-V/RM100-ND | Bluetooth Bluetooth v5.0 Transceiver Module 2.4GHz Integrated, Chip Surface Mount | 12.44 | No | Digi-Key
1 | XC1429TR-ND | XTAL OSC XO 14.7456MHZ CMOS SMD | 2.62 | No | Digi-Key
3 | 455-1579-1-ND | CONN HEADER SMD 3POS 1.25MM | 0.43564 | No | Digi-Key
3 | 455-3625-ND | 1.25mm JST female connector 3P | 1.22 | No | Digi-Key
4 | 478-5034-1-ND | Capacitor | 0.16684 | No | Digi-Key
12 | 36-5019CT-ND | Test Point, 1 Position SMD, RoHS, Tape and Reel | 0.31514 | No | Digi-Key

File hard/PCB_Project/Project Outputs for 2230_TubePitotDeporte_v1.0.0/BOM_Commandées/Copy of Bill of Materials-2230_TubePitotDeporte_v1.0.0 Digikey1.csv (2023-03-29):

2 | 455-1749-2-ND | Male Header, Pitch 2 mm, 1 x 2 Position, Height 5.5 mm, -25 to 85 degC, RoHS, Tape and Reel | 0.49125 | No | Digikey
2 | 4530-BSS138CT-ND | MOSFET N-CH 50V 220MA SOT-23 | 0.16 | No | Digikey

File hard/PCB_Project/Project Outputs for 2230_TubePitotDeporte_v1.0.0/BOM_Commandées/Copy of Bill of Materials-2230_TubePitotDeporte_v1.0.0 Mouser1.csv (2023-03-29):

1 | 410-ICM-42670-P | 6 axis IMU | 5.53 | No | Mouser
2 | 485-261 | 2mm JST female connector 2P | 0.69516 | No | Mouser
2 | 538-218112-0204 | 1.25mm JST female connector 2P | 1.78 | No | Mouser
2 | 595-TLV74333PDBVR | IC REG LINEAR 3.3V 300MA SOT23-5 | 0.34295 | No | Mouser
2 | 621-B260-F | Zener Diode | 0.40783 | No | Mouser
2 | 710-150080RS75000 | SMD mono-color Chip LED, WL-SMCW, Red | 0.17611 | No | Mouser
3 | 621-BAT46W-7-F | Zener Diode | 0.38002 | No | Mouser

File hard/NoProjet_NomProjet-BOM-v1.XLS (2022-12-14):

ETML
Refs | Nb | Désignation | Type | Valeur | Fournisseur | N° de commande | Prix u / 1 | Prix u / 10 | Prix u / 100 | Prix u / 1000 | Unité(s) d'emballage | Prix u / unité d'emballage | Prix de référence | Choix | Prix tot | Remarques
X1,X2 | 2 | Connecteur header pour câble plat DIN 41 651 sans bride de rétension | 3421-7600 | 20 pôles | Sasco Spoerle | 238221 |  |  | 2.450 | 2.150 | 100 | 2.450 | / un emb | * | 4.900 | p 3-23.002
 |  |  |  |  |  |  |  |  |  |  |  |  | -
 | 0.14 | m de câble plat 20 pôles | 3365-20 | 20 pôles | Sasco Spoerle | 270327 | 2.050 |  | 1.10 | 0.860 | 91m | 1.100 | / un emb | * | 0.154 | p3-26.029
 |  |  |  |  |  |  |  |  |  |  |  |  | -
 | 1 | montage |  |  | CIP |  |  |  |  |  |  |  | -
 |  |  |  |  | GXE |  |  | 4.000 | 3.000 |  |  |  | / 10 | * | 4.000
 |  |  |  |  |  |  |  |  |  |  |  |  | - | * | 0
 |  |  |  |  |  |  |  |  |  |  |  |  | -
 |  |  |  |  |  |  |  |  |  |  |  |  | - | * | 0
 |  |  |  |  |  |  |  |  |  |  |  |  | -
 |  |  |  |  |  |  |  |  |  |  |  |  | - | * | 0
 |  |  |  |  |  |  |  |  |  |  |  |  | -
 |  |  |  |  |  |  |  |  |  |  |  |  | - | * | 0
 |  |  |  |  |  |  |  |  |  |  |  |  | -
 |  |  |  |  |  |  |  |  |  |  |  |  | - | * | 0
 |  |  |  |  |  |  |  |  |  |  |  |  | -
 |  |  |  |  |  |  |  |  |  |  |  |  | - | * | 0
 |  |  |  |  |  |  |  |  |  |  |  |  | -
 |  |  |  |  |  |  |  |  |  |  |  |  | - | * | 0
 |  |  |  |  |  |  |  |  |  |  |  |  | -
 |  |  |  |  |  |  |  |  |  |  |  |  | - | * | 0
 |  |  |  |  |  |  |  |  |  |  |  |  | -
 |  |  |  |  |  |  |  |  |  |  |  |  | - | * | 0
 |  |  |  |  |  |  |  |  |  |  |  |  | -
 |  |  |  |  |  |  |  |  |  |  |  |  | - | * | 0
 |  |  |  |  |  |  |  |  |  |  |  |  | -
 |  |  |  |  |  |  |  |  |  |  |  |  | - | * | 0
 |  |  |  |  |  |  |  |  |  |  |  |  | -
 |  |  |  |  |  |  |  |  |  |  |  |  | - | * | 0
 |  |  |  |  |  |  |  |  |  |  |  |  | -
 |  |  |  |  |  |  |  |  |  |  |  |  | - | * | 0
 |  |  |  |  |  |  |  |  |  |  |  |  | -
 |  |  |  |  |  |  |  |  |  |  |  |  | - | * | 0
 |  |  |  |  |  |  |  |  |  |  |  |  | -
 |  |  |  |  |  |  |  |  |  |  |  |  | - | * | 0
 |  |  |  |  |  |  |  |  |  |  |  |  | -
 |  |  |  |  |  |  |  |  |  |  |  |  | - | * | 0
 |  |  |  |  |  |  |  |  |  |  |  |  | -
 |  |  |  |  |  |  |  |  |  |  |  |  | - | * | 0
 |  |  |  |  |  |  |  |  |  |  |  |  | -
 |  |  |  |  |  |  |  |  |  |  |  |  |  | Total: | 9.05

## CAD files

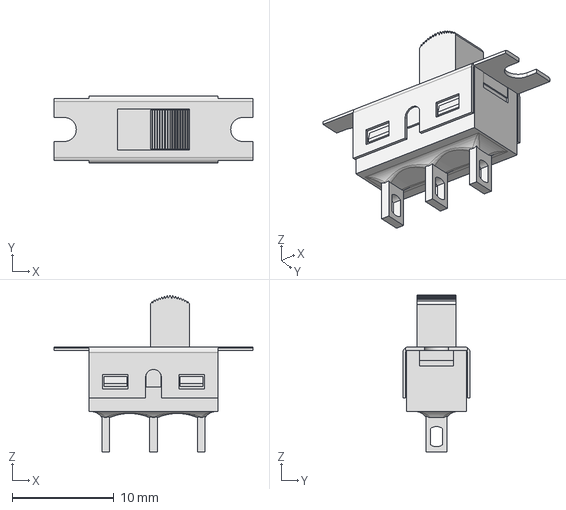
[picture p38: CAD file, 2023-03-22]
hard/PCB_Project/3D/500SSP1S1M1QEB--3DModel-STEP-520916.STEP
19.6 x 6.60 x 15.4 mm

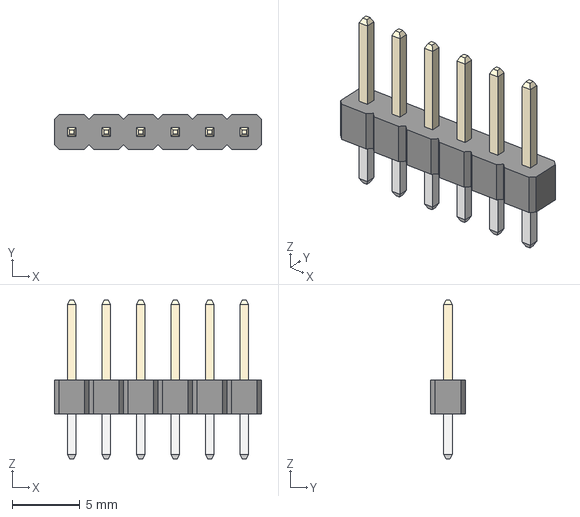
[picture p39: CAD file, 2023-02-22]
hard/PCB_Project/3D/1x6 TH Vert 100mil.step
15.2 x 2.54 x 11.7 mm

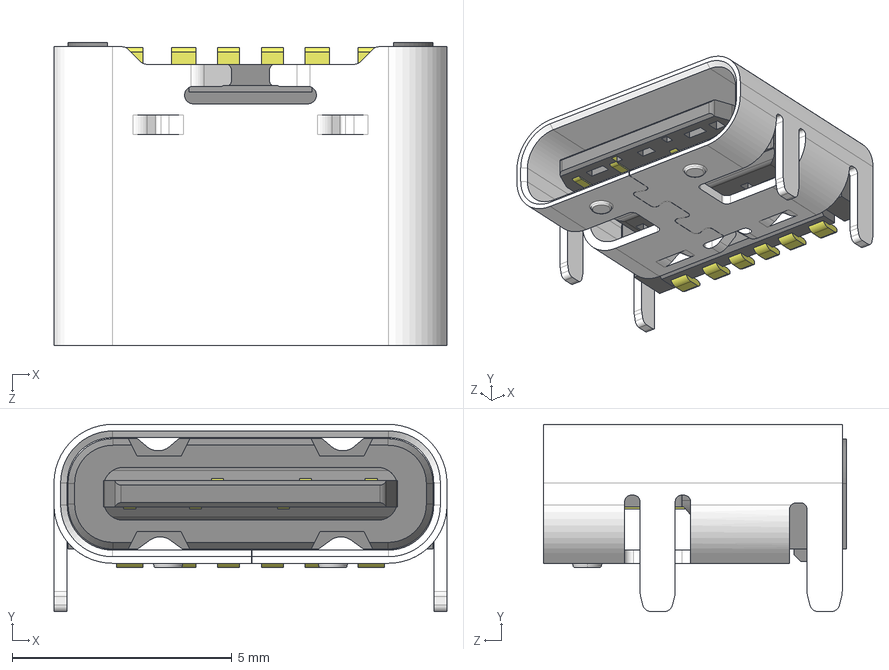
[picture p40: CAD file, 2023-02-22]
hard/PCB_Project/3D/CUI_DEVICES_UJC-HP-3-SMT-TR.step
8.94 x 4.26 x 6.90 mm

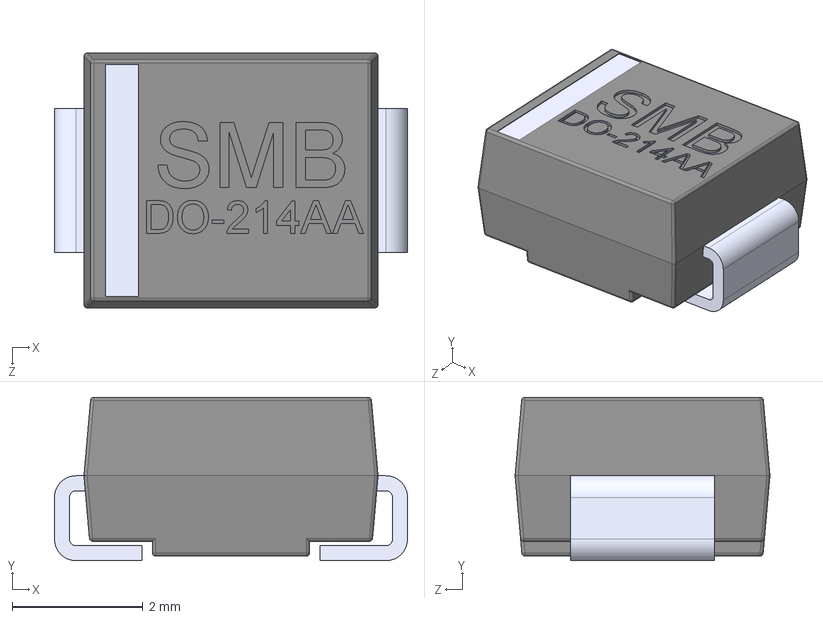
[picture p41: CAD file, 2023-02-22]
hard/PCB_Project/3D/SMB (DO-214AA).STEP
5.40 x 2.50 x 3.90 mm

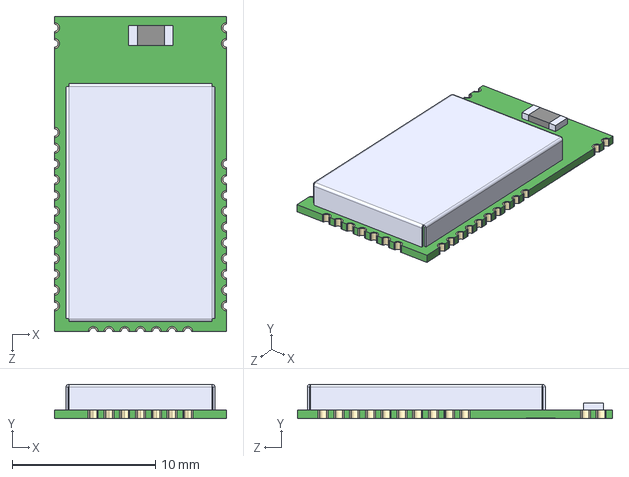
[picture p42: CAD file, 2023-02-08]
hard/PCB_Project/3D/RM100--3DModel-STEP-56544.STEP
12.0 x 2.40 x 22.0 mm

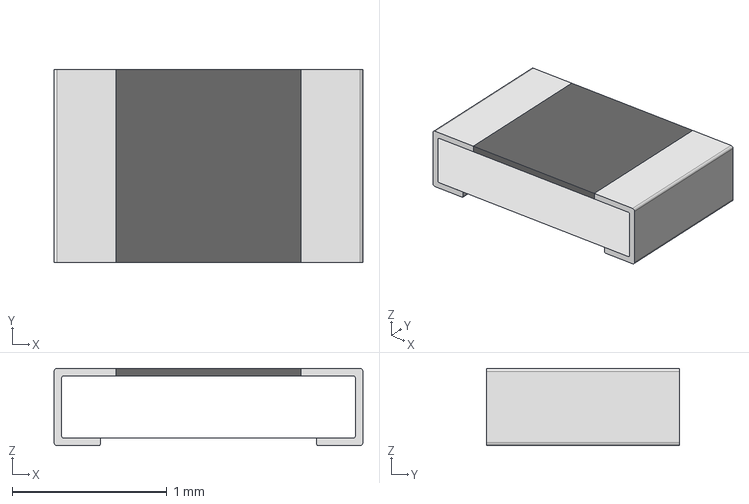
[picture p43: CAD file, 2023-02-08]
hard/PCB_Project/3D/RES0805.stp
2.00 x 1.25 x 0.5 mm

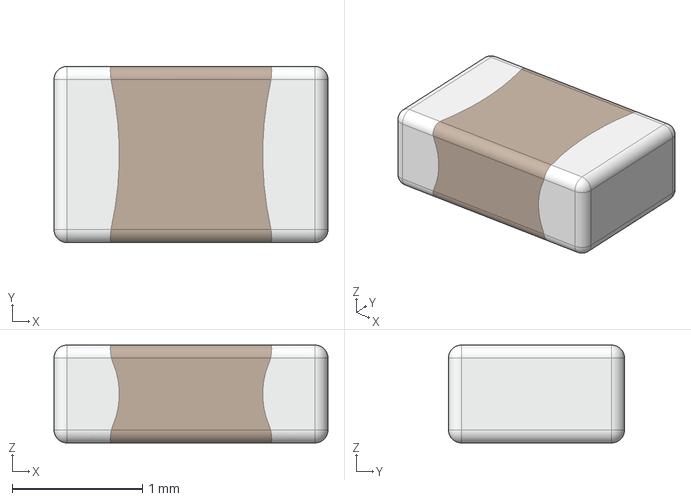
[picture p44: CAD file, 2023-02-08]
hard/PCB_Project/3D/CAPC-0805-T0.75-BN.stp
2.10 x 1.35 x 0.75 mm

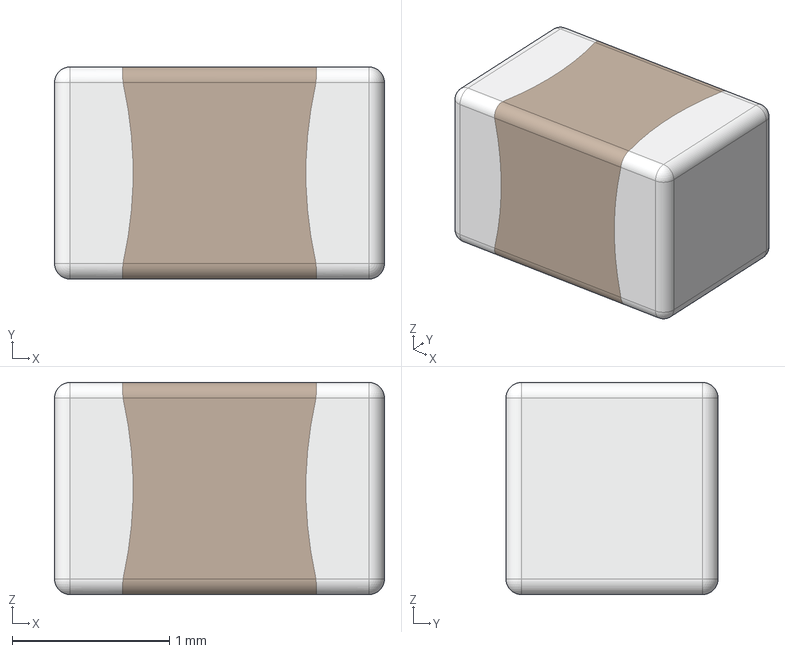
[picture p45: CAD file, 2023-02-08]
hard/PCB_Project/3D/CAPC-0805-T1.35-BN.stp
2.10 x 1.35 x 1.35 mm

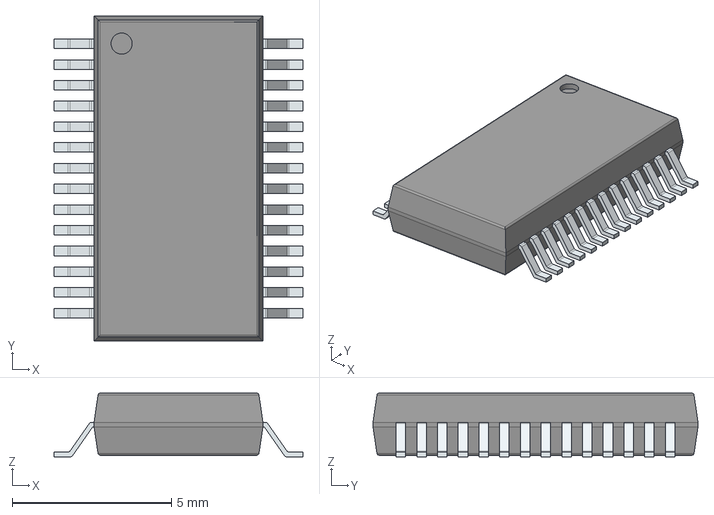
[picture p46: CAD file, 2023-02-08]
hard/PCB_Project/3D/PIC32MX130F064B-I_SS.stp
7.80 x 10.2 x 2.00 mm
PinsArrayLR

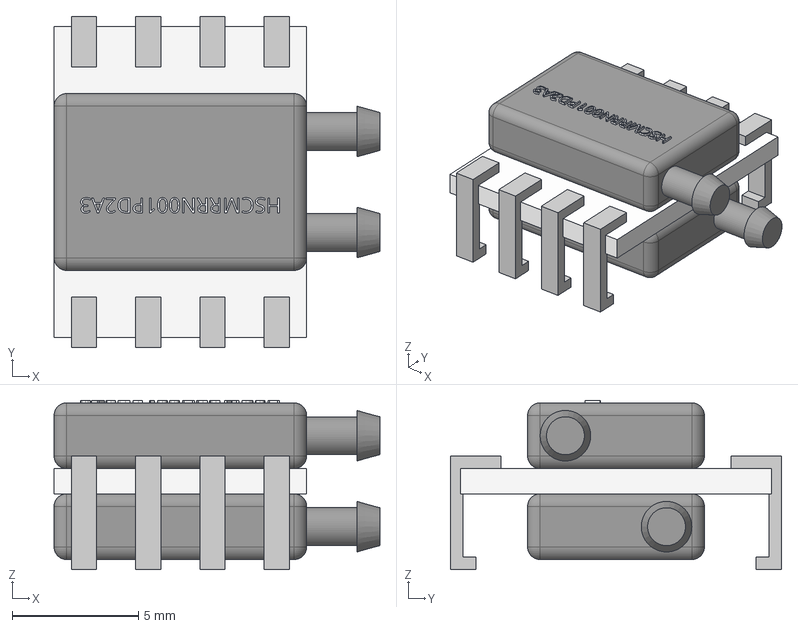
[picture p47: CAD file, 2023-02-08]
hard/PCB_Project/3D/HSCMRRN001PD2A3.step
12.9 x 13.1 x 6.70 mm

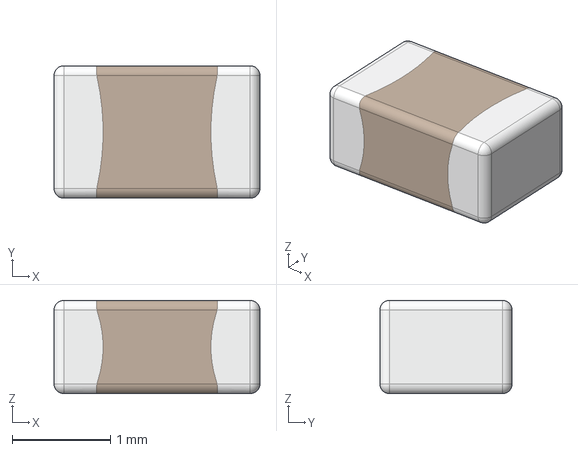
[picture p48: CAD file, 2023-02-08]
hard/PCB_Project/3D/CAPC-0805-T0.95-BN.stp
2.10 x 1.35 x 0.95 mm

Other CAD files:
hard/Meca/FRONT Case.x_t
hard/Meca/MID Case.x_t
hard/Meca/REAR case BAT.x_t
hard/Meca/REAR case TUR.x_t

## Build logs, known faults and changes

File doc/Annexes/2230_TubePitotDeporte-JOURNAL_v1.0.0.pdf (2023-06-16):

Jour | Date | Nbr période | Tâches effectuées
Mercredi | 16.11.2022 | 8 | ‐ (Présentation des projets et choix)
Jeudi | 17.11.2022 | 4 | Rédaction du cahier des charges (but du projet, schéma de principe, schéma bloc)
Mercredi | 23.11.2022 | 8 | Rédaction du cahier des charges (déscription simples des blocs,
Jeudi | 24.11.2022 | 4 | Rédaction du cahier des charges (croquis mécanique, tâches à réaliser, deadlines principales, planning, livrables)
Samedi | 26.11.2022 | 1 | Rencontre de M. Vincent Seguin à l'aéroprt de Lausanne pour plus de détail
Mercredi | 30.11.2022 | 8 | Finitiones du cahier des charges (corrections et amélioration de certain points), rédaction de la pré‐étude (contexte, schéma de principe, schéma bloc détaillé)
Samedi | 03.11.2022 | 5 | Rédaction de la pré‐étude (description des blocs détaillées)
Mercredi | 07.12.2022 | 8 | Rédaction de la pré‐étude (description des blocs détaillées)
Mercredi | 14.12.2022 | 8 | Présentation de la pré‐étude, début du design électronique, corrections de certains points de la pré‐étude
Mercredi | 21.12.2022 | 8 | Recheche d'information sur la génération d'électicité avec un moteur DC
Lundi | 26.12.2022 | 4 | Caractéistation du moteur DC RF‐370A‐15370
Mercredi | 11.01.2023 | 8 | Création du projet Altium et début du schéma électrique avec dimentionnement des composants
Mercredi | 18.01.2023 | 8 | Dimentionnement et choix de composants et design du schéma électriques
Dimanche | 22.01.2023 | 4 | Rédaction du rapport et design du schéma électrique
Mardi | 24.01.2023 | 4 | Rédaction du rapport et corrections du schéma électrique
Mercredi | 25.01.2023 | 10 | Rédaction du rapport et corrections du schéma électrique
Jeudi | 26.01.2023 | 4 | Rédaction du rapport et corrections du schéma électrique
Mercredi | 01.02.2023 | 8 | Correction du rapport, création de la présentation, présentation du projet
Mercredi | 08.02.2023 | 8 | Correction des points évoqués lors de la présentation, création de footprints
Jeudi | 16.02.2023 | 2 | Dessin d'une ébauche du boitier 3D
Mercredi | 22.02.2023 | 8 | Création de footprints, modification du schéma et début du placement des composants
Mercredi | 01.03.2023 | 6 | Recherche de solutions mécaniques au niveau du boitier et du PCB et placement des composants
Mardi | 07.03.2023 | 2 | Placement des composants
Mercredi | 08.03.2023 | 8 | Placement des composants et routage du PCB
Jeudi | 09.03.2023 | 2 | Routage du PCB
Samedi | 11.03.2023 | 4 | Routage du PCB
Mercredi | 15.03.2023 | 8 | Routage du PCB, contrôle du PCB par Ali Zoubir et modification de la BOM
Dimanche | 19.03.2023 | 4 | Design mecanique du boitier
Mercredi | 22.03.2023 | 8 | Recherche des composants non critiques (inserts, LED 5mm, ..) et modification de la BOM
Mercredi | 29.03.2023 | 8 | Finition du design mécanique du boitier
Mercredi | 05.03.2023 | 8 | Montage et test du PCB, configuration du MCU sur Harmony et programmation de test du MCU
Mardi | 11.04.2023 | 8 | Programmation de test du capteur de pressions différentielles et du module bluetooth
Mercredi | 12.04.2023 | 5 | Programmation du driver du capteur de pressions différentielles et du module bluetooth
Mercredi | 26.04.2023 | 8 | Mesure et test du reset en mode turbine, amelioration du système de reset
Mercredi | 03.05.2023 | 8 | Compréhention, test et programmation du driver de l'IMU
Mercredi | 10.05.2023 | 11 | Debugging du driver de l'IMU et debugging des permissions Android
Mercredi | 17,05,2023 | 10 | Debugging du driver de l'IMU
Mardi | 23.05.2023 | 3 | Mise en place de l'USART en FIFO
Mercredi | 24.05.2023 | 10 | Mise en place de l'USART en FIFO et modification du driver du module Bluetooth
Mercredi | 31.05.2023 | 8 | Correction de bugs et amélioration du code
Jeudi | 01.06.2023 | 2 | Correction de bugs et amélioration du code
Mercredi | 07.06.2023 | 8 | Correction de bugs et amélioration du code, recherche de documentation sur le développement d'application Android avec Bluetooth
Jeudi | 08.06.2023 | 3 | Développement de l'application Android
Mercredi | 14.06.2023 | 8 | Développement de l'application Android
Jeudi | 15.06.2023 | 6 | Finalisation du rapport et de la documentation
Vendredi | 16.06.2023 | 2 | Finalisation du rapport, de la documentation et rendu
| Total | 288

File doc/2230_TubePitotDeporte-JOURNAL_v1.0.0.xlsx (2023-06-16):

Jour | Date | Nbr période | Tâches effectuées
Mercredi | 2022-11-16 | 8 | - (Présentation des projets et choix)
Jeudi | 2022-11-17 | 4 | Rédaction du cahier des charges (but du projet, schéma de principe, schéma bloc)
Mercredi | 2022-11-23 | 8 | Rédaction du cahier des charges (déscription simples des blocs,
Jeudi | 2022-11-24 | 4 | Rédaction du cahier des charges (croquis mécanique, tâches à réaliser, deadlines principales, planning, livrables)
Samedi | 2022-11-26 | 1 | Rencontre de M. Vincent Seguin à l'aéroprt de Lausanne pour plus de détail
Mercredi | 2022-11-30 | 8 | Finitiones du cahier des charges (corrections et amélioration de certain points), rédaction de la pré-étude (contexte, schéma de principe, schéma bloc détaillé)
Samedi | 2022-11-03 | 5 | Rédaction de la pré-étude (description des blocs détaillées)
Mercredi | 2022-12-07 | 8 | Rédaction de la pré-étude (description des blocs détaillées)
Mercredi | 2022-12-14 | 8 | Présentation de la pré-étude, début du design électronique, corrections de certains points de la pré-étude
Mercredi | 2022-12-21 | 8 | Recheche d'information sur la génération d'électicité avec un moteur DC
Lundi | 2022-12-26 | 4 | Caractéistation du moteur DC RF-370A-15370
Mercredi | 2023-01-11 | 8 | Création du projet Altium et début du schéma électrique avec dimentionnement des composants
Mercredi | 2023-01-18 | 8 | Dimentionnement et choix de composants et design du schéma électriques
Dimanche | 2023-01-22 | 4 | Rédaction du rapport et design du schéma électrique
Mardi | 2023-01-24 | 4 | Rédaction du rapport et corrections du schéma électrique
Mercredi | 2023-01-25 | 10 | Rédaction du rapport et corrections du schéma électrique
Jeudi | 2023-01-26 | 4 | Rédaction du rapport et corrections du schéma électrique
Mercredi | 2023-02-01 | 8 | Correction du rapport, création de la présentation, présentation du projet
Mercredi | 2023-02-08 | 8 | Correction des points évoqués lors de la présentation, création de footprints
Jeudi | 2023-02-16 | 2 | Dessin d'une ébauche du boitier 3D
Mercredi | 2023-02-22 | 8 | Création de footprints, modification du schéma et début du placement des composants
Mercredi | 2023-03-01 | 6 | Recherche de solutions mécaniques au niveau du boitier et du PCB et placement des composants
Mardi | 2023-03-07 | 2 | Placement des composants
Mercredi | 2023-03-08 | 8 | Placement des composants et routage du PCB
Jeudi | 2023-03-09 | 2 | Routage du PCB
Samedi | 2023-03-11 | 4 | Routage du PCB
Mercredi | 2023-03-15 | 8 | Routage du PCB, contrôle du PCB par Ali Zoubir et modification de la BOM
Dimanche | 2023-03-19 | 4 | Design mecanique du boitier
Mercredi | 2023-03-22 | 8 | Recherche des composants non critiques (inserts, LED 5mm, ..) et modification de la BOM
Mercredi | 2023-03-29 | 8 | Finition du design mécanique du boitier
Mercredi | 2023-03-05 | 8 | Montage et test du PCB, configuration du MCU sur Harmony et programmation de test du MCU
Mardi | 2023-04-11 | 8 | Programmation de test du capteur de pressions différentielles et du module bluetooth
Mercredi | 2023-04-12 | 5 | Programmation du driver du capteur de pressions différentielles et du module bluetooth
Mercredi | 2023-04-26 | 8 | Mesure et test du reset en mode turbine, amelioration du système de reset
Mercredi | 2023-05-03 | 8 | Compréhention, test et programmation du driver de l'IMU
Mercredi | 2023-05-10 | 11 | Debugging du driver de l'IMU et debugging des permissions Android
Mercredi | 17,05,2023 | 10 | Debugging du driver de l'IMU
Mardi | 2023-05-23 | 3 | Mise en place de l'USART en FIFO
Mercredi | 2023-05-24 | 10 | Mise en place de l'USART en FIFO et modification du driver du module Bluetooth
Mercredi | 2023-05-31 | 8 | Correction de bugs et amélioration du code
Jeudi | 2023-06-01 | 2 | Correction de bugs et amélioration du code
Mercredi | 2023-06-07 | 8 | Correction de bugs et amélioration du code, recherche de documentation sur le développement d'application Android avec Bluetooth
Jeudi | 2023-06-08 | 3 | Développement de l'application Android
Mercredi | 2023-06-14 | 8 | Développement de l'application Android
Jeudi | 2023-06-15 | 6 | Finalisation du rapport et de la documentation
Vendredi | 2023-06-16 | 2 | Finalisation du rapport, de la documentation et rendu
 | Total | 288

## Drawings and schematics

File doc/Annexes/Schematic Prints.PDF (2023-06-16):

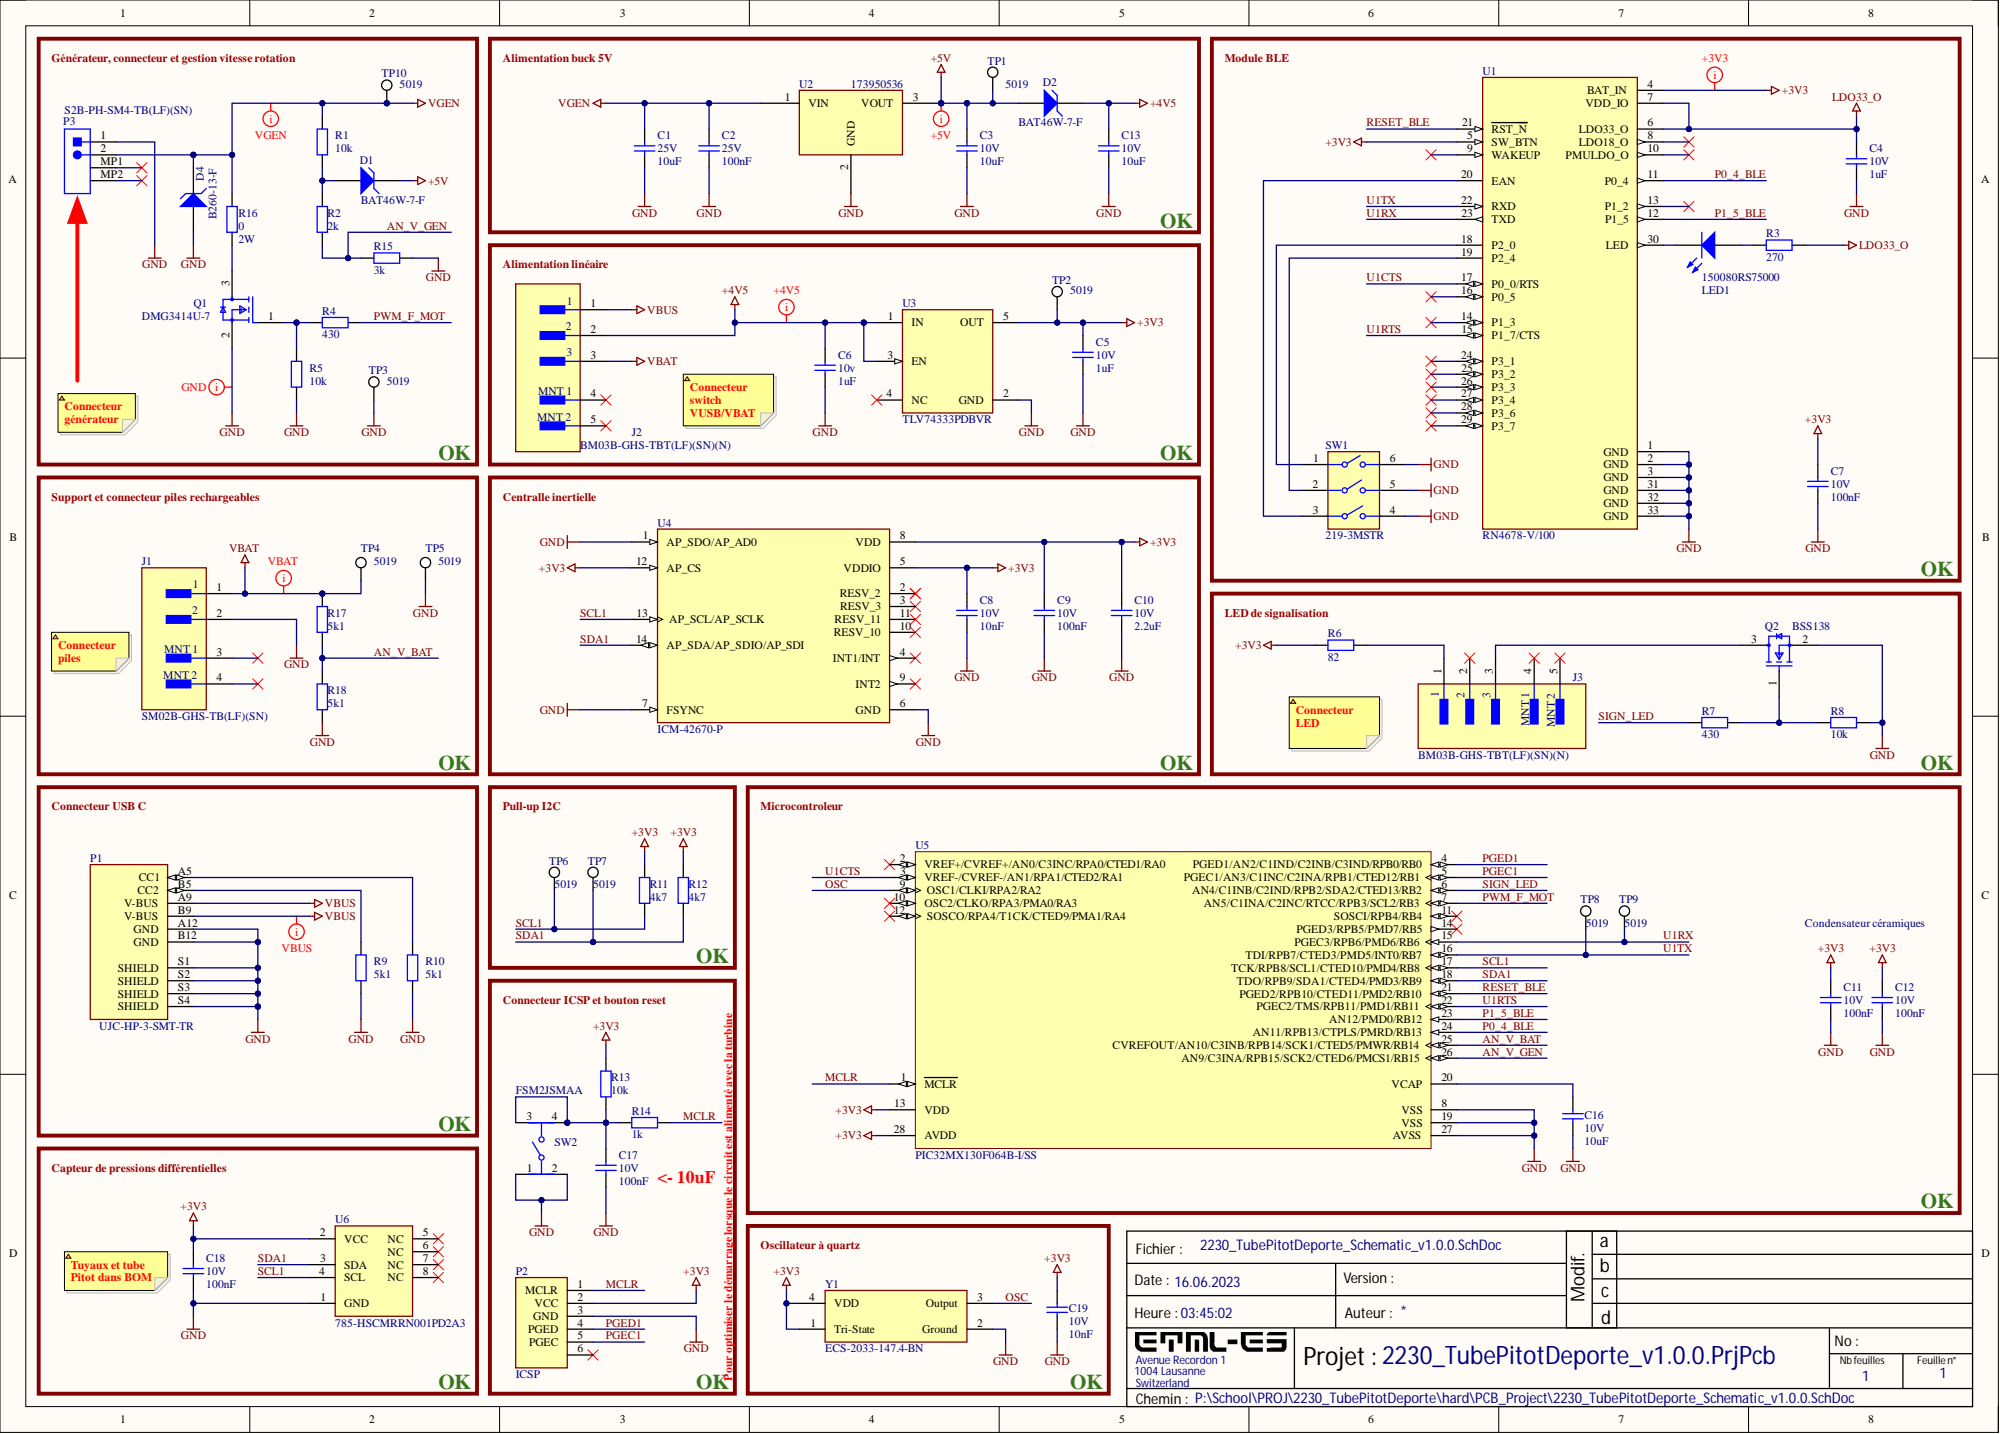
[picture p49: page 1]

Générateur, connecteur et gestion vitesse rotation

BM03B-GHS-TBT(LF)(SN)(N)

Support et connecteur piles rechargeables

SM02B-GHS-TB(LF)(SN)

Connecteur ICSP et bouton reset

UJC-HP-3-SMT-TR

Pour optimiser le démarrage lorsque le circuit est alimenté avec la turbine

Capteur de pressions différentielles

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

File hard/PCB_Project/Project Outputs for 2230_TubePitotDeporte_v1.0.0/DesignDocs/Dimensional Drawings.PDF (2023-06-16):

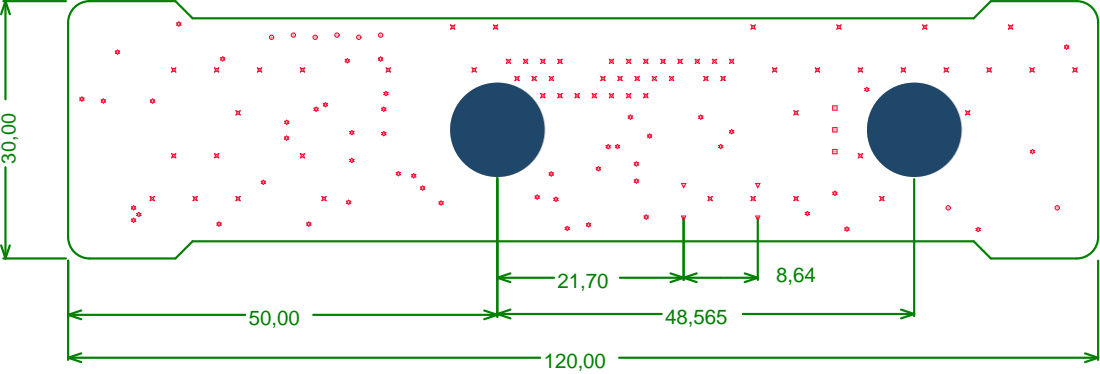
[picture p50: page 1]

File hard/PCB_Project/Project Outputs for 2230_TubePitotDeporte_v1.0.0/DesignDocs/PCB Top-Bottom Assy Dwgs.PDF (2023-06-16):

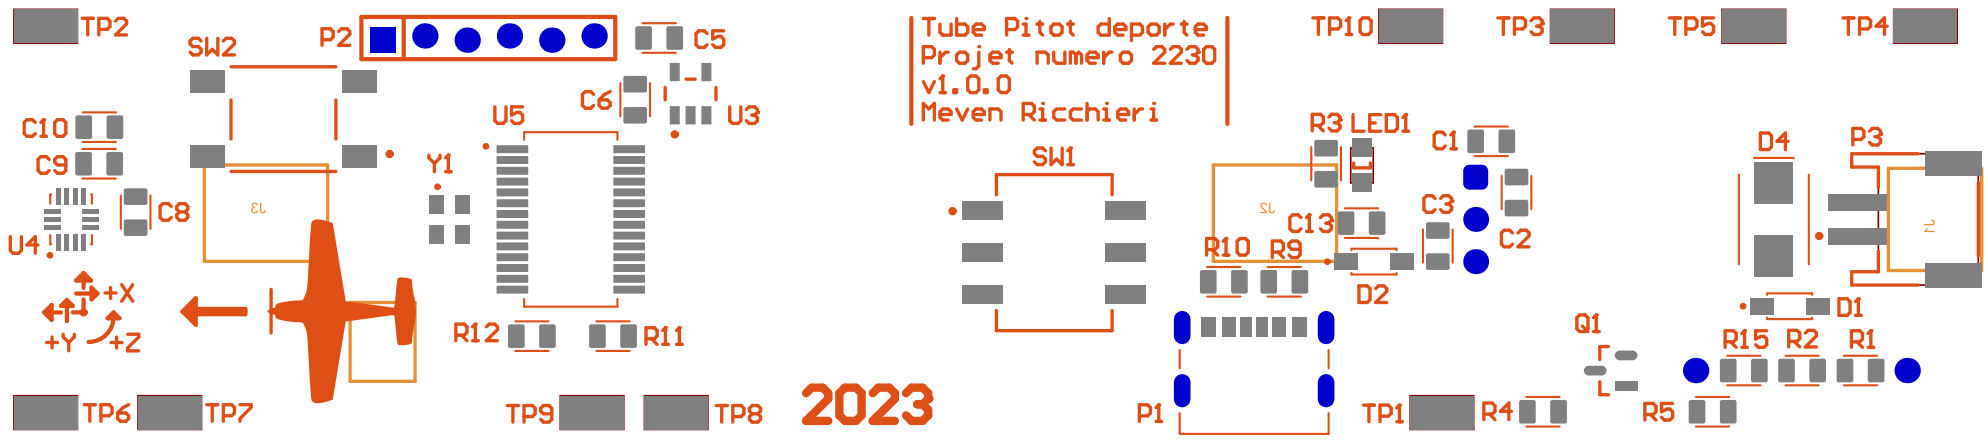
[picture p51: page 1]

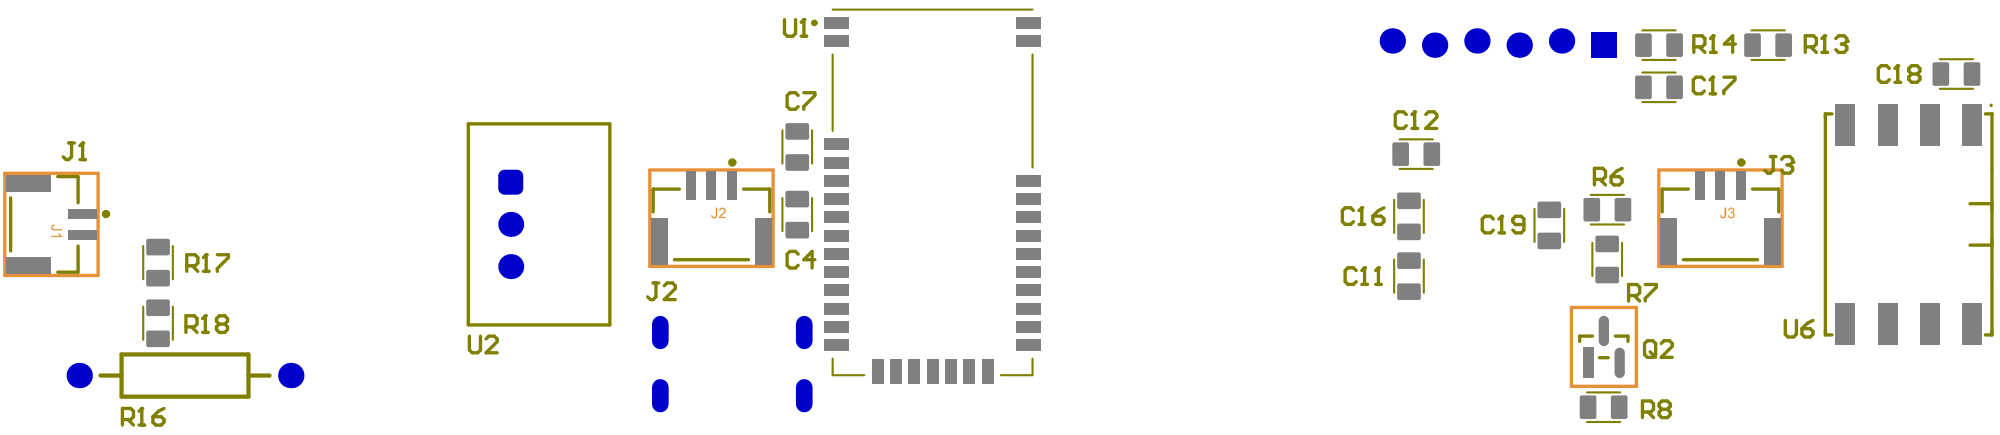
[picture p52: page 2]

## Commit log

2022-12-14 Initial files
    [2230_TubePitotDeporte-JOURNAL_v1.0.0.xlsx, 2230_TubePitotDeporte-PLANNING_v1.0.0.xlsx, NoProjet_NomProjet-BOM-v1.XLS]
2023-01-11 PCB project created
    [2230_TubePitotDeporte-JOURNAL_v1.0.0.xlsx, 2230_TubePitotDeporte_Library_v1.0.0.SchLib, 2230_TubePitotDeporte_Schematic_v1.0.0.SchDoc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]
2023-01-18 Some updates of the schematic
    [2230_TubePitotDeporte_Library_v1.0.0.SchLib, 2230_TubePitotDeporte_Schematic_v1.0.0.SchDoc, 2230_TubePitotDeporte_v1.0.0.PrjPcb]
2023-01-18 Small modification
    [2230_TubePitotDeporte_Schematic_v1.0.0.SchDoc]
2023-01-19 Some updades
    [2230_TubePitotDeporte_Library_v1.0.0.SchLib, 2230_TubePitotDeporte_Schematic_v1.0.0.SchDoc]
2023-01-23 Schematic almost done
    [2230_TubePitotDeporte_Schematic_v1.0.0.SchDoc]
2023-01-24 Fixed some points of the schematic
    [2230_TubePitotDeporte-JOURNAL_v1.0.0.xlsx, 2230_TubePitotDeporte_Library_v1.0.0.SchLib, 2230_TubePitotDeporte_Schematic_v1.0.0.SchDoc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]
2023-01-25 Almost done
    [2230_TubePitotDeporte_Schematic_v1.0.0.SchDoc, 2230_TubePitotDeporte_v1.0.0.PrjPcb]
2023-01-26 Schema DONE
    [2230_TubePitotDeporte-JOURNAL_v1.0.0.xlsx, 2230_TubePitotDeporte_Schematic_v1.0.0.SchDoc, 2230_TubePitotDeporte_v1.0.0.PrjPcb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]
2023-02-01 Presentation done!
    [2230_TubePitotDeporte_Schematic_v1.0.0.SchDoc, Moteur_RF-370CA_mesures.xlsx]
2023-02-02 Small updates
    [2230_TubePitotDeporte-JOURNAL_v1.0.0.xlsx, 2230_TubePitotDeporte_Schematic_v1.0.0.SchDoc]
2023-02-08 Majority of footprints added
    [2230_TubePitotDeporte_Library_v1.0.0.PcbLib, 2230_TubePitotDeporte_Library_v1.0.0.SchLib, 2230_TubePitotDeporte_Schematic_v1.0.0.SchDoc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]
2023-02-22 Schematic done!!!!
    [1x6 TH Vert 100mil.step, 2230_TubePitotDeporte-JOURNAL_v1.0.0.xlsx, 2230_TubePitotDeporte_Library_v1.0.0.PcbLib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]
2023-03-15 pcb almost done
    [2230_TubePitotDeporte_Library_v1.0.0.PcbLib, 2230_TubePitotDeporte_Schematic_v1.0.0.SchDoc, 2230_TubePitotDeporte_v1.0.0.PrjPcb]
2023-03-15 PCB done, BOM not ready
    [2230_TubePitotDeporte-JOURNAL_v1.0.0.xlsx, 2230_TubePitotDeporte-PLANNING_v1.0.0.xlsx, 2230_TubePitotDeporte_Library_v1.0.0.PcbLib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]
2023-03-22 PCB Done and sent to manufacturer
    [2230_TubePitotDeporte_PCB_v1.0.0_Board_Outline_(ES).gbr, 2230_TubePitotDeporte_PCB_v1.0.0_Copper_Signal_Bot.gbr, 2230_TubePitotDeporte_PCB_v1.0.0_Copper_Signal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]
2023-03-29 journal updated
    [2230_TubePitotDeporte-JOURNAL_v1.0.0.xlsx]
2023-05-24 Journal update
    [2230_TubePitotDeporte-JOURNAL_v1.0.0.xlsx]
2023-06-16 Final 16.06.2023
    [2230_TubePitotDeporte-JOURNAL_v1.0.0.xlsx, 2230_TubePitotDeporte-PLANNING_v1.0.0.xlsx, 2230_TubePitotDeporte_Schematic_v1.0.0.SchDoc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]
2023-07-30 Mechanical parts
    [FRONT Case.x_t, MID Case.x_t, REAR case BAT.x_t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]
